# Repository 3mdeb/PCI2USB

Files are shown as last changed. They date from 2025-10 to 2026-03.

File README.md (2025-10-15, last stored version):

CERN Open Hardware Licence v1.2 or later

Preamble

Through this CERN Open Hardware Licence ("CERN OHL") version 1.2, CERN
wishes to provide a tool to foster collaboration and sharing among
hardware designers.  The CERN OHL is copyright CERN. Anyone is welcome
to use the CERN OHL, in unmodified form only, for the distribution of
their own Open Hardware designs. Any other right is reserved. Release
of hardware designs under the CERN OHL does not constitute an
endorsement of the licensor or its designs nor does it imply any
involvement by CERN in the development of such designs.

1. Definitions

In this Licence, the following terms have the following meanings:
 
“Licence” means this CERN OHL.

“Documentation” means schematic diagrams, designs, circuit or circuit
board layouts, mechanical drawings, flow charts and descriptive text,
and other explanatory material that is explicitly stated as being made
available under the conditions of this Licence. The Documentation may
be in any medium, including but not limited to computer files and
representations on paper, film, or any other media.

“Documentation Location” means a location where the Licensor has
placed Documentation, and which he believes will be publicly
accessible for at least three years from the first communication to
the public or distribution of Documentation.

“Product” means either an entire, or any part of a, device built using
the Documentation or the modified Documentation.

“Licensee” means any natural or legal person exercising rights under
this Licence.

“Licensor” means any natural or legal person that creates or modifies
Documentation and subsequently communicates to the public and/ or
distributes the resulting Documentation under the terms and conditions
of this Licence.

A Licensee may at the same time be a Licensor, and vice versa. 

Use of the masculine gender includes the feminine and neuter genders
and is employed solely to facilitate reading.

2. Applicability

2.1. This Licence governs the use, copying, modification,
communication to the public and distribution of the Documentation, and
the manufacture and distribution of Products. By exercising any right
granted under this Licence, the Licensee irrevocably accepts these
terms and conditions.

2.2. This Licence is granted by the Licensor directly to the Licensee,
and shall apply worldwide and without limitation in time. The Licensee
may assign his licence rights or grant sub-licences.

2.3. This Licence does not extend to software, firmware, or code
loaded into programmable devices which may be used in conjunction with
the Documentation, the modified Documentation or with Products, unless
such software, firmware, or code is explicitly expressed to be subject
to this Licence. The use of such software, firmware, or code is
otherwise subject to the applicable licence terms and conditions.

3. Copying, modification, communication to the public and distribution
of the Documentation

3.1. The Licensee shall keep intact all copyright and trademarks
notices, all notices referring to Documentation Location, and all
notices that refer to this Licence and to the disclaimer of warranties
that are included in the Documentation. He shall include a copy
thereof in every copy of the Documentation or, as the case may be,
modified Documentation, that he communicates to the public or
distributes.

3.2. The Licensee may copy, communicate to the public and distribute
verbatim copies of the Documentation, in any medium, subject to the
requirements specified in section 3.1.

3.3. The Licensee may modify the Documentation or any portion thereof
provided that upon modification of the Documentation, the Licensee
shall make the modified Documentation available from a Documentation
Location such that it can be easily located by an original Licensor
once the Licensee communicates to the public or distributes the
modified Documentation under section 3.4, and, where required by
section 4.1, by a recipient of a Product. However, the Licensor shall
not assert his rights under the foregoing proviso unless or until a
Product is distributed.

3.4. The Licensee may communicate to the public and distribute the
modified Documentation (thereby in addition to being a Licensee also
becoming a Licensor), always provided that he shall:

a) comply with section 3.1;

b) cause the modified Documentation to carry prominent notices stating
that the Licensee has modified the Documentation, with the date and
description of the modifications;

c) cause the modified Documentation to carry a new Documentation
Location notice if the original Documentation provided for one;

d) make available the modified Documentation at the same level of
abstraction as that of the Documentation, in the preferred format for
making modifications to it (e.g. the native format of the CAD tool as
applicable), and in the event that format is proprietary, in a format
viewable with a tool licensed under an OSI-approved license if the
proprietary tool can create it; and

e) license the modified Documentation under the terms and conditions
of this Licence or, where applicable, a later version of this Licence
as may be issued by CERN.

3.5. The Licence includes a non-exclusive licence to those patents or
registered designs that are held by, under the control of, or
sub-licensable by the Licensor, to the extent necessary to make use of
the rights granted under this Licence. The scope of this section 3.5
shall be strictly limited to the parts of the Documentation or
modified Documentation created by the Licensor.

4. Manufacture and distribution of Products

4.1. The Licensee may manufacture or distribute Products always
provided that, where such manufacture or distribution requires a
licence under this Licence the Licensee provides to each recipient of
such Products an easy means of accessing a copy of the Documentation
or modified Documentation, as applicable, as set out in section 3.

4.2. The Licensee is invited to inform any Licensor who has indicated
his wish to receive this information about the type, quantity and
dates of production of Products the Licensee has (had) manufactured

5. Warranty and liability

5.1. DISCLAIMER – The Documentation and any modified Documentation are
provided "as is" and any express or implied warranties, including, but
not limited to, implied warranties of merchantability, of satisfactory
quality, non-infringement of third party rights, and fitness for a
particular purpose or use are disclaimed in respect of the
Documentation, the modified Documentation or any Product. The Licensor
makes no representation that the Documentation, modified
Documentation, or any Product, does or will not infringe any patent,
copyright, trade secret or other proprietary right. The entire risk as
to the use, quality, and performance of a Product shall be with the
Licensee and not the Licensor. This disclaimer of warranty is an
essential part of this Licence and a condition for the grant of any
rights granted under this Licence. The Licensee warrants that it does
not act in a consumer capacity.

5.2. LIMITATION OF LIABILITY – The Licensor shall have no liability
for direct, indirect, special, incidental, consequential, exemplary,
punitive or other damages of any character including, without
limitation, procurement of substitute goods or services, loss of use,
data or profits, or business interruption, however caused and on any
theory of contract, warranty, tort (including negligence), product
liability or otherwise, arising in any way in relation to the
Documentation, modified Documentation and/or the use, manufacture or
distribution of a Product, even if advised of the possibility of such
damages, and the Licensee shall hold the Licensor(s) free and harmless
from any liability, costs, damages, fees and expenses, including
claims by third parties, in relation to such use.

6. General

6.1. Except for the rights explicitly granted hereunder, this Licence
does not imply or represent any transfer or assignment of intellectual
property rights to the Licensee.

6.2. The Licensee shall not use or make reference to any of the names
(including acronyms and abbreviations), images, or logos under which
the Licensor is known, save in so far as required to comply with
section 3. Any such permitted use or reference shall be factual and
shall in no event suggest any kind of endorsement by the Licensor or
its personnel of the modified Documentation or any Product, or any
kind of implication by the Licensor or its personnel in the
preparation of the modified Documentation or Product.

6.3. CERN may publish updated versions of this Licence which retain
the same general provisions as this version, but differ in detail so
far this is required and reasonable. New versions will be published
with a unique version number.

6.4. This Licence shall terminate with immediate effect, upon written
notice and without involvement of a court if the Licensee fails to
comply with any of its terms and conditions, or if the Licensee
initiates legal action against Licensor in relation to this
Licence. Section 5 shall continue to apply.

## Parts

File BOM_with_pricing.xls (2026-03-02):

 | References | Description | Mfr | Mfr PN | Value | Footprint | Quantity | Datasheet | Price per Unit(1) | Price per Unit(100) | TOTAL(1) | TOTAL(100)
1 | C1, C2, C3, C7, C34, C56 | X5R, 10%, 6.3V | Samsung Electro-Mechanics | CL21A226KQCLRNC | 22 μF | 0805 | 6 | https://www.samsungsem.com/resources/file/global/support/product_catalog/MLCC.pdf | 0.48 PLN | 0.15 PLN | 2.88 PLN | 0.90 PLN
2 | C17, C18, C19, C20, C21 | X5R, 10%, 6.3V | Samsung Electro-Mechanics | CL05A226MQ5N6J8 | 22 μF | 0402 | 5 | https://mm.digikey.com/Volume0/opasdata/d220001/medias/docus/61/CL05A226MQ5N6J8_Spec.pdf | 1.81 PLN | 1.36 PLN | 9.05 PLN | 6.80 PLN
3 | C12, C13 | Electrolytic, 20%, 10V | Panasonic | EEE-FK1A151P | 150 μF | 6,3 mm x 5.8 mm | 2 | https://industrial.panasonic.com/cdbs/www-data/pdf/RDE0000/ABA0000C1184.pdf | 1.81 PLN | 0.74 PLN | 3.62 PLN | 1.48 PLN
4 | C16 | X7R, 10%, 10V | Vishay | VJ0402Y102KXQCW1BC | 1000 pF | 0402 | 1 | https://www.vishay.com/doc?28548 | 0.44 PLN | 0.11 PLN | 0.44 PLN | 0.11 PLN
5 | C22, C25, C28, C31, C37, C40, C43, C46, C49, C57 | X7R, 10%, 6.3V | Murata Electronics | GRM155R70J103KA01D | 0.01 μF | 0402 | 10 | https://search.murata.co.jp/Ceramy/image/img/A01X/G101/ENG/GRM155R70J103KA01-01A.pdf | 0.37 PLN | 0.06 PLN | 3.70 PLN | 0.60 PLN
6 | C35, C36 | X8R, 10%, 10V | KEMET | C0402C180K8HACAUTO | 18 pF | 0402 | 2 | https://www.mouser.pl/datasheet/3/508/1/KEM_C1007_X8R_ULTRA_150C_SMD.pdf | 0.40 PLN | 0.11 PLN | 0.80 PLN | 0.22 PLN
7 | C4 | X7R, 10%, 6.3V | Murata Electronics | GRM21BR70J106KA73K | 10 μF | 0805 | 1 | https://search.murata.co.jp/Ceramy/image/img/A01X/G101/ENG/GRM21BR70J106KA73-01A.pdf | 0.48 PLN | 0.15 PLN | 0.48 PLN | 0.15 PLN
8 | C5 | NOT POPULATED | - | - | - | 0402 | 0 | - | 0.00 PLN | 0.00 PLN | 0.00 PLN | 0.00 PLN
9 | C6, C8, C9, C10, C11, C14, C15, C23, C24, C26, C27, C29, C30, C32, C33 C41, C42, C44, C45, C47, C48, C50, C51, C52, C53, C54, C55 | X7R, 10%, 6.3V | Murata Electronics | GRM155R70J104KA01D | 0.1 μF | 0402 | 26 | https://www.mouser.pl/datasheet/3/76/1/GRM155R70J104KA01-01A.pdf | 0.37 PLN | 0.06 PLN | 9.62 PLN | 1.56 PLN
10 | D2 | 110pF, 120W | Panjit | PJSD05TS-AU_R1_000A1 | 6V/9V/5A | SOD-523-2 | 1 | https://www.mouser.pl/datasheet/3/3736/1/FFA64C26C476D1F4CE6B232A1F1091977EEA37920C5E016FF7236D6CCD3F512B.pdf | 0.63 PLN | 0.20 PLN | 0.63 PLN | 0.20 PLN
11 | D3 | 300pF, 120W | Panjit | PJSD03TS-AU_R1_000A1 | 4V/6.5V/5A | SOD-523-2 | 1 | https://www.mouser.pl/datasheet/3/3736/1/3946363437334643344438333636453735383137424443343037353234384636.pdf | 0.85 PLN | 0.27 PLN | 0.85 PLN | 0.27 PLN
12 | D4 | LED, RED | Kingbright | APHD1608LSURCK | RED | 0603 | 1 | https://www.mouser.pl/datasheet/3/308/1/APHD1608LSURCK.pdf | 1.26 PLN | 0.60 PLN | 1.26 PLN | 0.60 PLN
13 | D6, D7 | LED, GREEN | Kingbright | APHD1608LCGCK | GREEN | 0603 | 2 | https://www.mouser.pl/datasheet/3/308/1/APHD1608LCGCK.pdf | 1.37 PLN | 0.65 PLN | 2.74 PLN | 1.30 PLN
14 | D8 | 2.3pF, 85W | Texas Instruments | ESDS304DBVR | 3.6V/4.5V/16A | SOT-23-5 | 1 | https://www.ti.com/lit/ds/symlink/esds302.pdf?ts=1764697688544 | 3.22 PLN | 1.30 PLN | 3.22 PLN | 1.30 PLN
15 | F1, F2 | Fast Act Fuse | Vishay | MFU0603FF05000P500 | 32VDC/5A | 0603 | 2 | https://www.vishay.com/docs/28747/mfuserie.pdf | 0.85 PLN | 0.60 PLN | 1.70 PLN | 1.20 PLN
16 | F3 | Fast Act Fuse | Vishay | MFU0603FF01000P500 | 32VDC/1A | 0603 | 1 | https://www.vishay.com/doc?28747 | 0.78 PLN | 0.55 PLN | 0.78 PLN | 0.55 PLN
17 | FB1 | Ferrite Bead | Murata | BLM18EG221SN1D | 220 Ohm, 2A | 0603 | 1 | https://www.mouser.pl/datasheet/3/76/1/ENFA0021.pdf | 0.85 PLN | 0.42 PLN | 0.85 PLN | 0.42 PLN
18 | FL1, FL2 | 25%, 5V | Panasonic | EXC-24CE900U | 90 Ohm 160mA | 0504 | 2 | https://industrial.panasonic.com/cdbs/www-data/pdf/AWE0000/AWE0000C207.pdf | 1.44 PLN | 0.98 PLN | 2.88 PLN | 1.96 PLN
19 | IC1 | USB HOST IC | Texas Instruments | TUSB7320 | 2 Port USB 3.0 | WQFN-100 | 1 | https://www.ti.com/lit/ds/symlink/tusb7340.pdf | 43.34 PLN | 29.03 PLN | 43.34 PLN | 29.03 PLN
20 | J1 | M.2 Edge Connector | - | - | - | - | 0 | - | 0.00 PLN | 0.00 PLN | 0.00 PLN | 0.00 PLN
21 | J2 | USB Internal Connector | Samtec | TSW-105-07-G-D-009 | 9 pin | 2.54mm pitch | 1 | https://suddendocs.samtec.com/catalog_english/tsw_th.pdf | 5.29 PLN | 3.29 PLN | 5.29 PLN | 3.29 PLN
22 | L1 | 20%, 5A | Pulse Electronics | BMRA000505151R0MA1 | 1 μH | 5.7 mm x 5.4 mm x 1.5 mm | 1 | https://www.mouser.pl/datasheet/3/508/1/BMRx_Series.pdf | 1.96 PLN | 1.33 PLN | 1.96 PLN | 1.33 PLN
23 | R1 | 1%, 200mW | Panasonic | ERJ-P03F7323V | 732Kohm | 0603 | 1 | https://industrial.panasonic.com/cdbs/www-data/pdf/RDO0000/AOA0000C331.pdf | 1.04 PLN | 0.33 PLN | 1.04 PLN | 0.33 PLN
24 | R10 | 1%, 100mW | Panasonic | ERJ-U02F9091X | 9.09 Kohm | 0402 | 1 | https://industrial.panasonic.com/cdbs/www-data/pdf/RDP0000/AOA0000C334.pdf | 0.44 PLN | 0.08 PLN | 0.44 PLN | 0.08 PLN
25 | R11, R12, R13, R14 | NOT POPULATED | - | - | - | 0402 | 0 | - | 0.00 PLN | 0.00 PLN | 0.00 PLN | 0.00 PLN
26 | R15, R16 | NOT POPULATED | - | - | - | 0402 | 0 | - | 0.00 PLN | 0.00 PLN | 0.00 PLN | 0.00 PLN
27 | R17 | 1%, 100mW | Panasonic | ERJ-2RKF3092X | 30.9 Kohm | 0402 | 1 | https://industrial.panasonic.com/cdbs/www-data/pdf/RDA0000/AOA0000C304.pdf | 0.37 PLN | 0.03 PLN | 0.37 PLN | 0.03 PLN
28 | R2, R29 | 5%, 200mW | Panasonic | ERJ-PA2J104X | 100 Kohm | 0402 | 2 | https://industrial.panasonic.com/cdbs/www-data/pdf/RDO0000/AOA0000C331.pdf | 0.48 PLN | 0.20 PLN | 0.96 PLN | 0.40 PLN
29 | R20, R21 | 1%, 63mW | Vishay | CRCW0402680RFKEDC | 680 Ohm | 0402 | 2 | https://www.vishay.com/docs/20035/dcrcwe3.pdf | 0.37 PLN | 0.04 PLN | 0.74 PLN | 0.08 PLN
30 | R22 | NOT POPULATED | - | - | - | 0402 | 0 | - | 0.00 PLN | 0.00 PLN | 0.00 PLN | 0.00 PLN
31 | R24, R25, R28 | 1%, 100mW | Panasonic | ERJ-2GE0R00X | 0 Ohm | 0402 | 3 | https://industrial.panasonic.com/cdbs/www-data/pdf/RDA0000/AOA0000C301.pdf | 0.37 PLN | 0.03 PLN | 1.11 PLN | 0.09 PLN
32 | R27 | 1%, 100mW | Panasonic | ERJ-2RKF1004X | 1 Mohm | 0402 | 1 | https://industrial.panasonic.com/cdbs/www-data/pdf/RDA0000/AOA0000C304.pdf | 0.37 PLN | 0.03 PLN | 0.37 PLN | 0.03 PLN
33 | R4 | 1%, 63mW | Vishay | CRCW04021K50FKEDC | 1.5 Kohm | 0402 | 1 | https://www.vishay.com/docs/20035/dcrcwe3.pdf | 0.37 PLN | 0.04 PLN | 0.37 PLN | 0.04 PLN
34 | R5 | 0.05%, 62.5mW | Panasonic | ERJ-2RHD4991X | 4.99 Kohm | 0402 | 1 | https://industrial.panasonic.com/cdbs/www-data/pdf/RDA0000/AOA0000C304.pdf | 0.52 PLN | 0.11 PLN | 0.52 PLN | 0.11 PLN
35 | R6 | 1%, 100mW | Panasonic | ERJ-2RKF1871X | 1.87 Kohm | 0402 | 1 | https://industrial.panasonic.com/cdbs/www-data/pdf/RDA0000/AOA0000C304.pdf | 0.37 PLN | 0.04 PLN | 0.37 PLN | 0.04 PLN
36 | R7, R18, R19, R23 | 1%, 100mW | Panasonic | ERJ-2RKF1002X | 10 Kohm | 0402 | 4 | https://industrial.panasonic.com/cdbs/www-data/pdf/RDA0000/AOA0000C304.pdf | 0.40 PLN | 0.04 PLN | 1.60 PLN | 0.16 PLN
37 | R8, R26 | 1%, 100mW | Panasonic | ERJ-2RKF4701X | 4.7 Kohm | 0402 | 2 | https://industrial.panasonic.com/cdbs/www-data/pdf/RDA0000/AOA0000C304.pdf | 0.37 PLN | 0.04 PLN | 0.74 PLN | 0.08 PLN
38 | U1 | Boost Converter | Texas Instruments | TPS61023DRLR | 3.3V to 5V 3.7 A | SOT-563-6 | 1 | https://www.ti.com/lit/ds/symlink/tps61023.pdf | 4.07 PLN | 2.33 PLN | 4.07 PLN | 2.33 PLN
39 | U2 | Power Switch IC | Texas Instruments | TPS2560DRC | 2 Out, 5V, 2.5A | VSON-10 | 1 | https://www.ti.com/lit/ds/symlink/tps2560.pdf?ts=1763292158337 | 5.25 PLN | 3.08 PLN | 5.25 PLN | 3.08 PLN
40 | U3 | Voltage Regulator | Texas Instruments | TPS74401RGWRM3 | 3.3V to 1.1V 3 A | VQFN-20 | 1 | https://www.ti.com/lit/gpn/tps74401 | 6.97 PLN | 3.26 PLN | 6.97 PLN | 3.26 PLN
41 | Y1 | 18 pF, 50 Ohm | ABRACON | ABM3B-48.000MHZ-B2-T | 48 MHz | 5 mm x 3.2 mm | 1 | https://www.mouser.pl/datasheet/3/184/1/abm3b.pdf | 2.70 PLN | 1.93 PLN | 2.70 PLN | 1.93 PLN
 |  |  |  |  |  |  |  |  |  | Total: | 123.71 PLN | 65.34 PLN

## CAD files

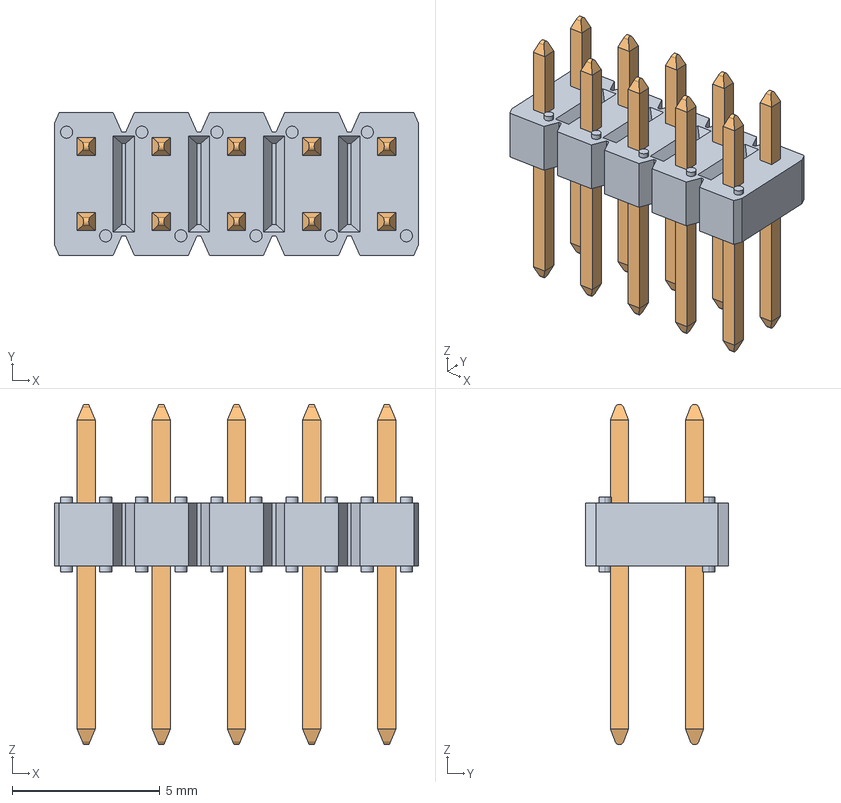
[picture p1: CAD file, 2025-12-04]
Kicad-Files/Custom Libraries/3dmodels/TSW-105-07-G-D-009.stp
12.3 x 4.83 x 11.5 mm
77310_Y16 x 10

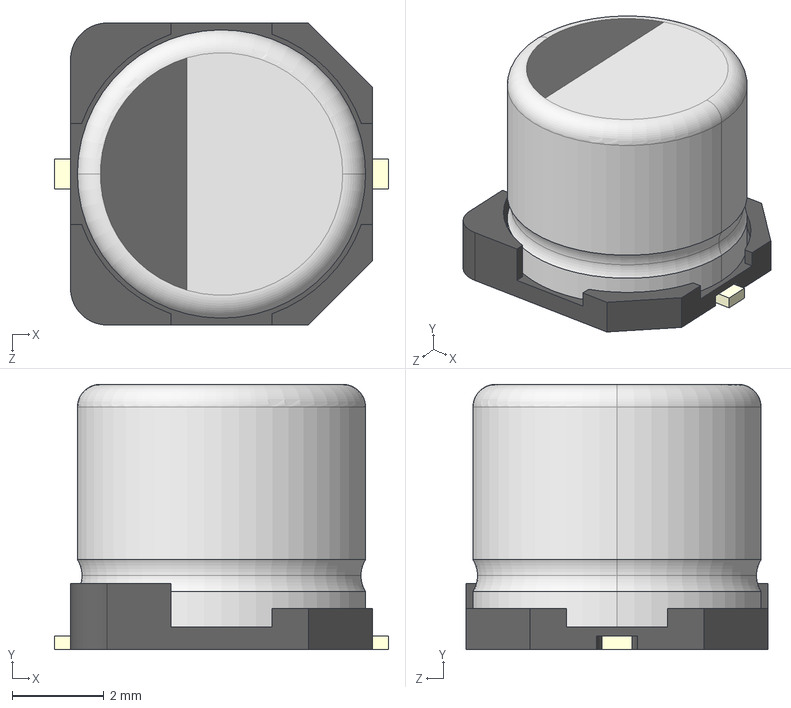
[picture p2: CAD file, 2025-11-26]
Kicad-Files/Custom Libraries/3dmodels/EEE-FK1A151P.stp
7.30 x 5.80 x 6.60 mm
標準SIZE CODE D-001
標準SIZE CODE D-002
標準SIZE CODE D-003 x 2

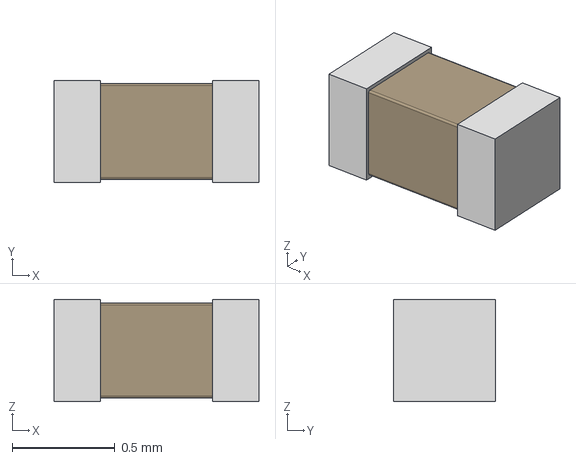
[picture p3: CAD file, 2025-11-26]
Kicad-Files/Custom Libraries/3dmodels/capacitor0402.stp
1.00 x 0.5 x 0.5 mm

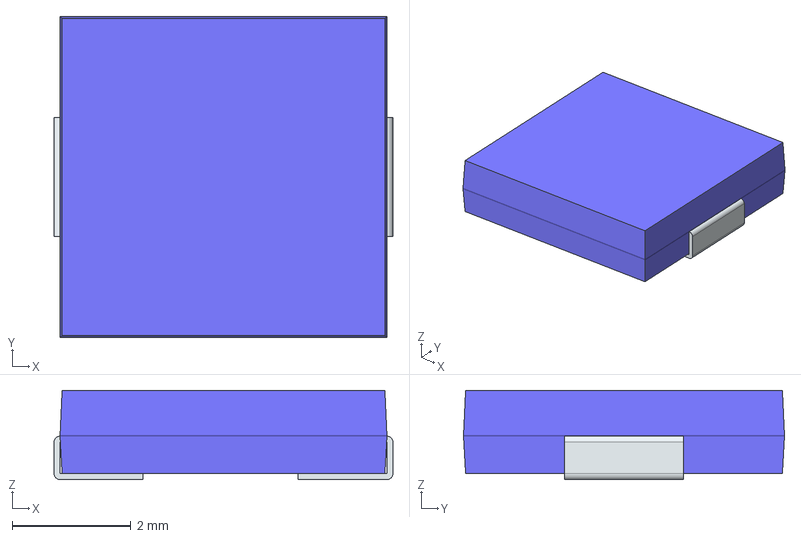
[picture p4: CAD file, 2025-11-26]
Kicad-Files/Custom Libraries/3dmodels/BMRA00050515R47MA1.stp
5.70 x 5.40 x 1.50 mm
FilletPin1
FilletPin2

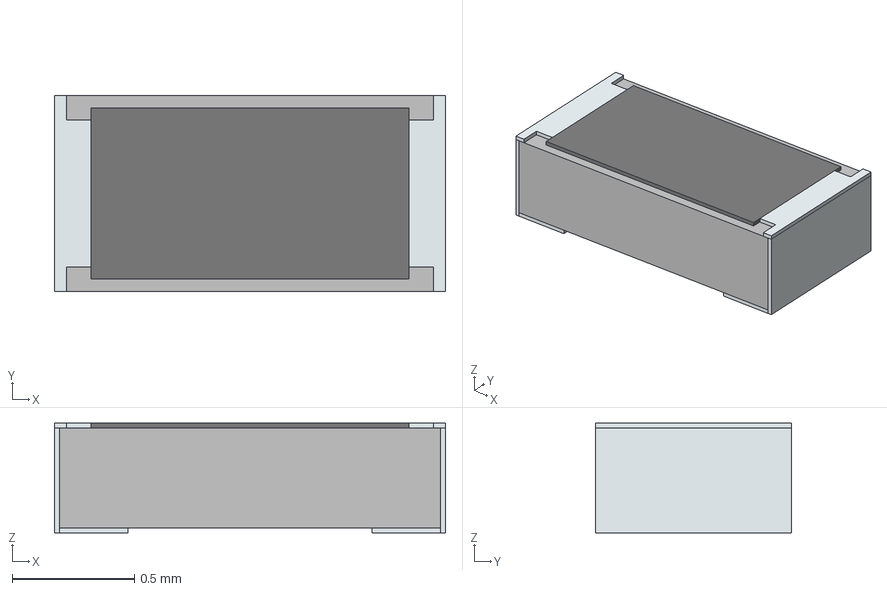
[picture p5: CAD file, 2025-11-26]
Kicad-Files/Custom Libraries/3dmodels/resistor0603.stp
1.60 x 0.8 x 0.45 mm
solidBody
solidTop
solidTerminal2
solidTerminal1
solidTerminal3

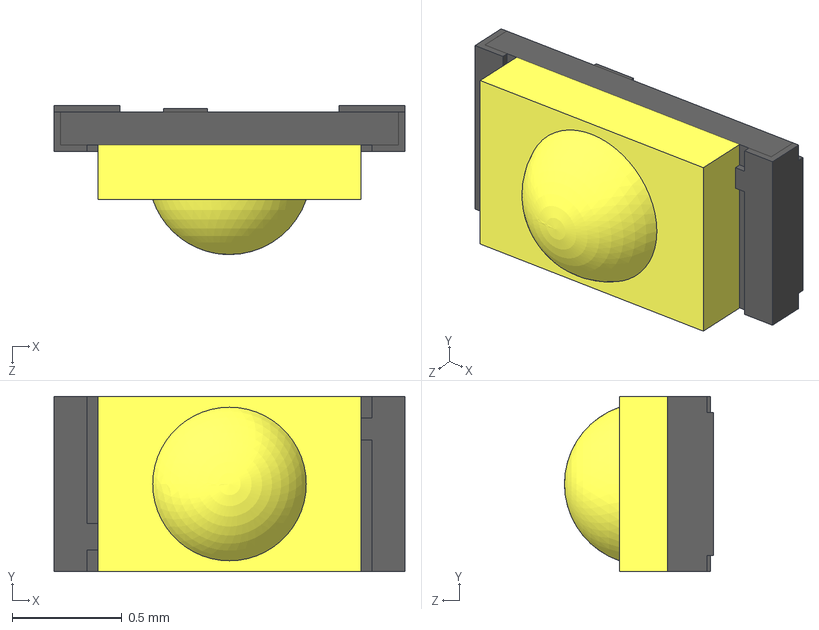
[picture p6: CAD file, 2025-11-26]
Kicad-Files/Custom Libraries/3dmodels/APHD1608LCGCK.stp
1.60 x 0.8 x 0.68 mm

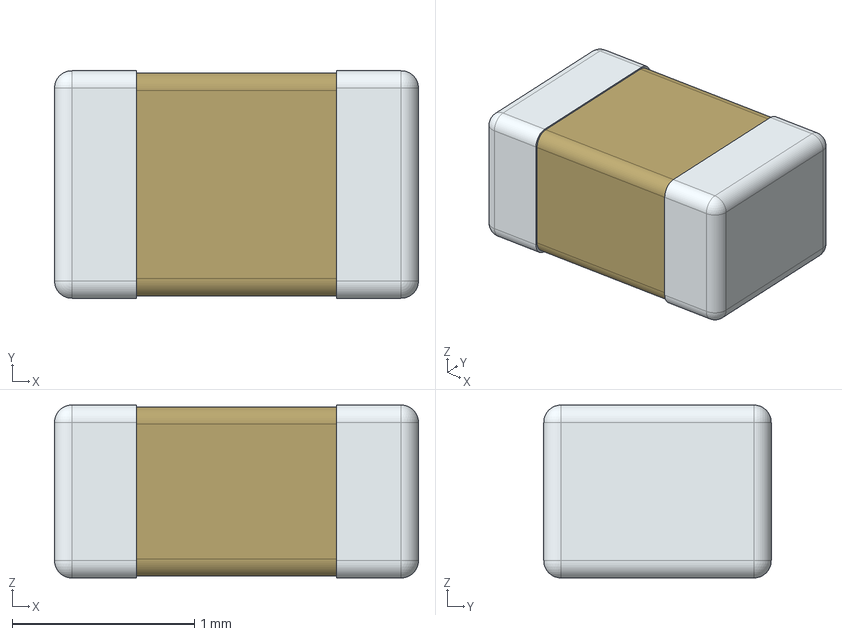
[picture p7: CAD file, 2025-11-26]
Kicad-Files/Custom Libraries/3dmodels/capacitor0805.stp
2.00 x 1.25 x 0.95 mm

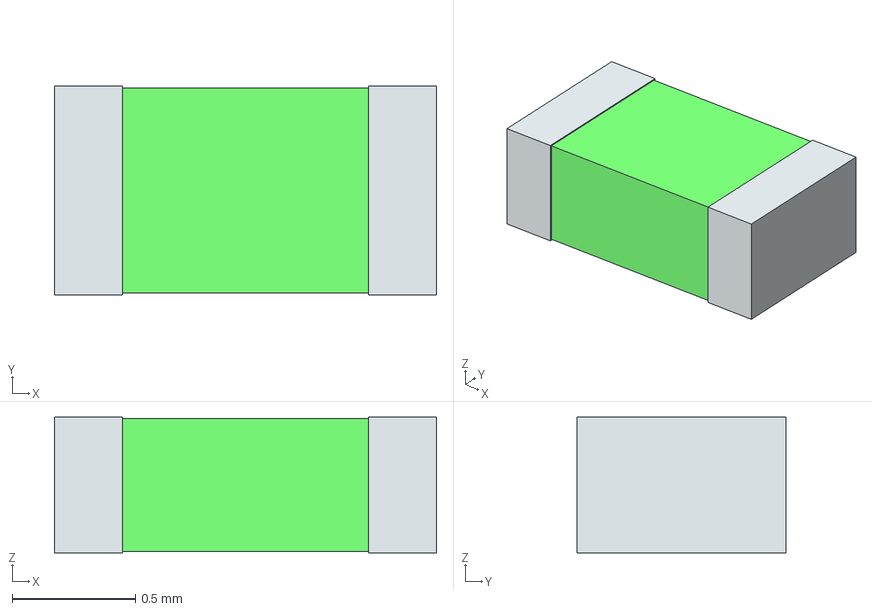
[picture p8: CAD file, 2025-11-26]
Kicad-Files/Custom Libraries/3dmodels/fuse0603.stp
1.55 x 0.85 x 0.55 mm
term1
term2

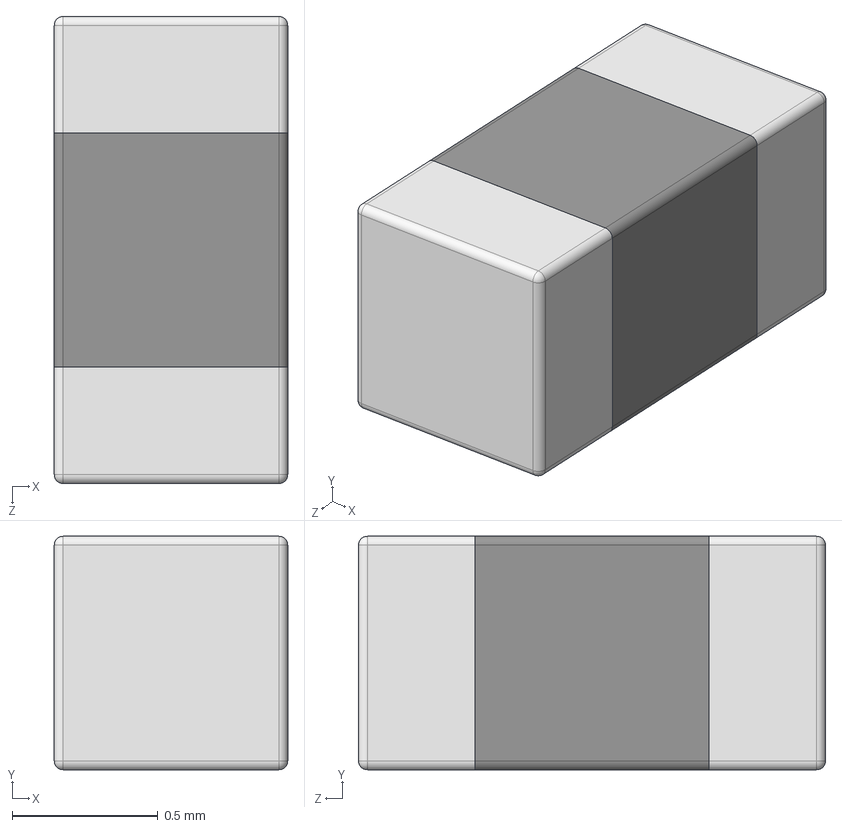
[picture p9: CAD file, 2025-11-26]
Kicad-Files/Custom Libraries/3dmodels/BLM18EG221SN1D.stp
0.8 x 0.8 x 1.60 mm

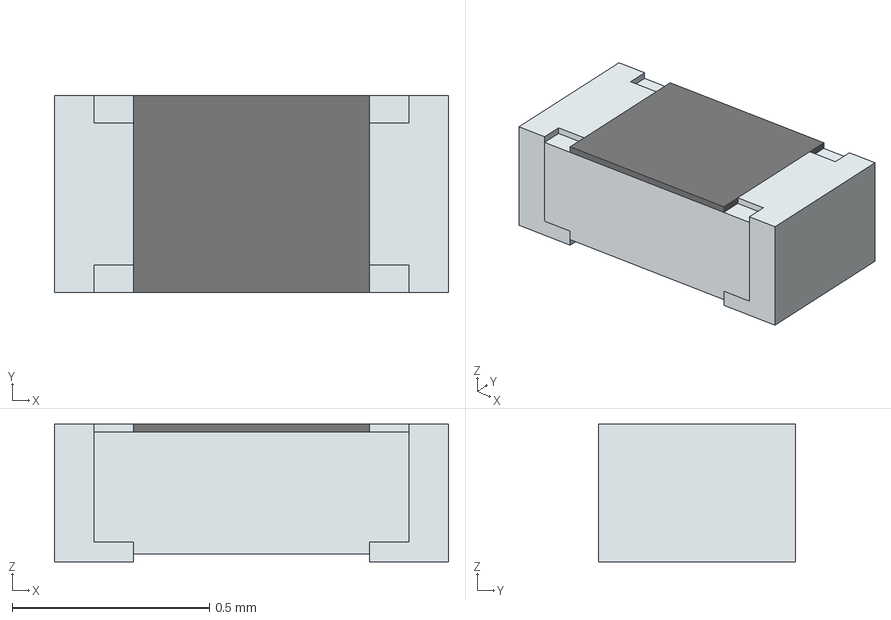
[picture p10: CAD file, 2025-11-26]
Kicad-Files/Custom Libraries/3dmodels/resistor0402.stp
1.00 x 0.5 x 0.35 mm
solidBody
Terminal
solidTop

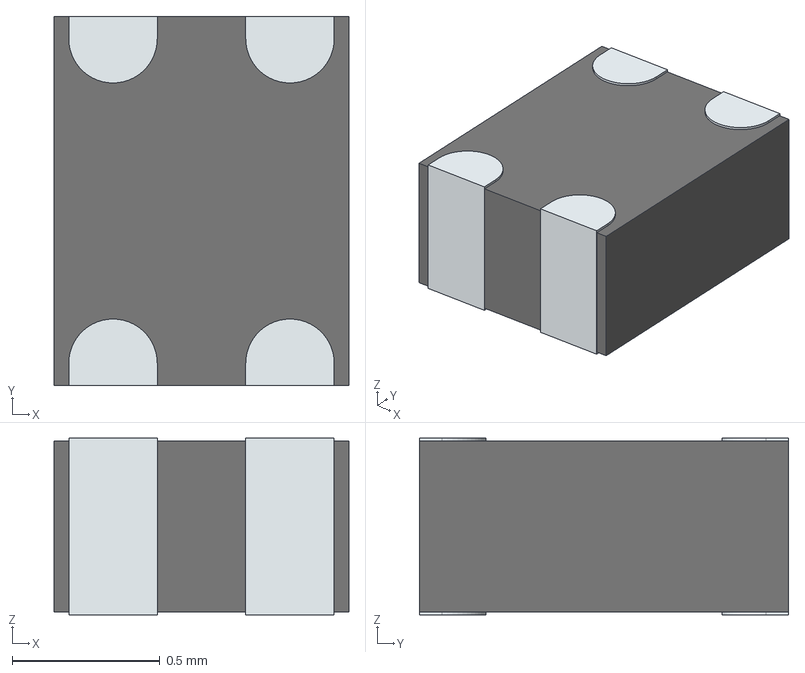
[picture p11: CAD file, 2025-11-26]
Kicad-Files/Custom Libraries/3dmodels/EXC-24CE900U.stp
1.00 x 1.25 x 0.6 mm
Rect1
solidTerminal

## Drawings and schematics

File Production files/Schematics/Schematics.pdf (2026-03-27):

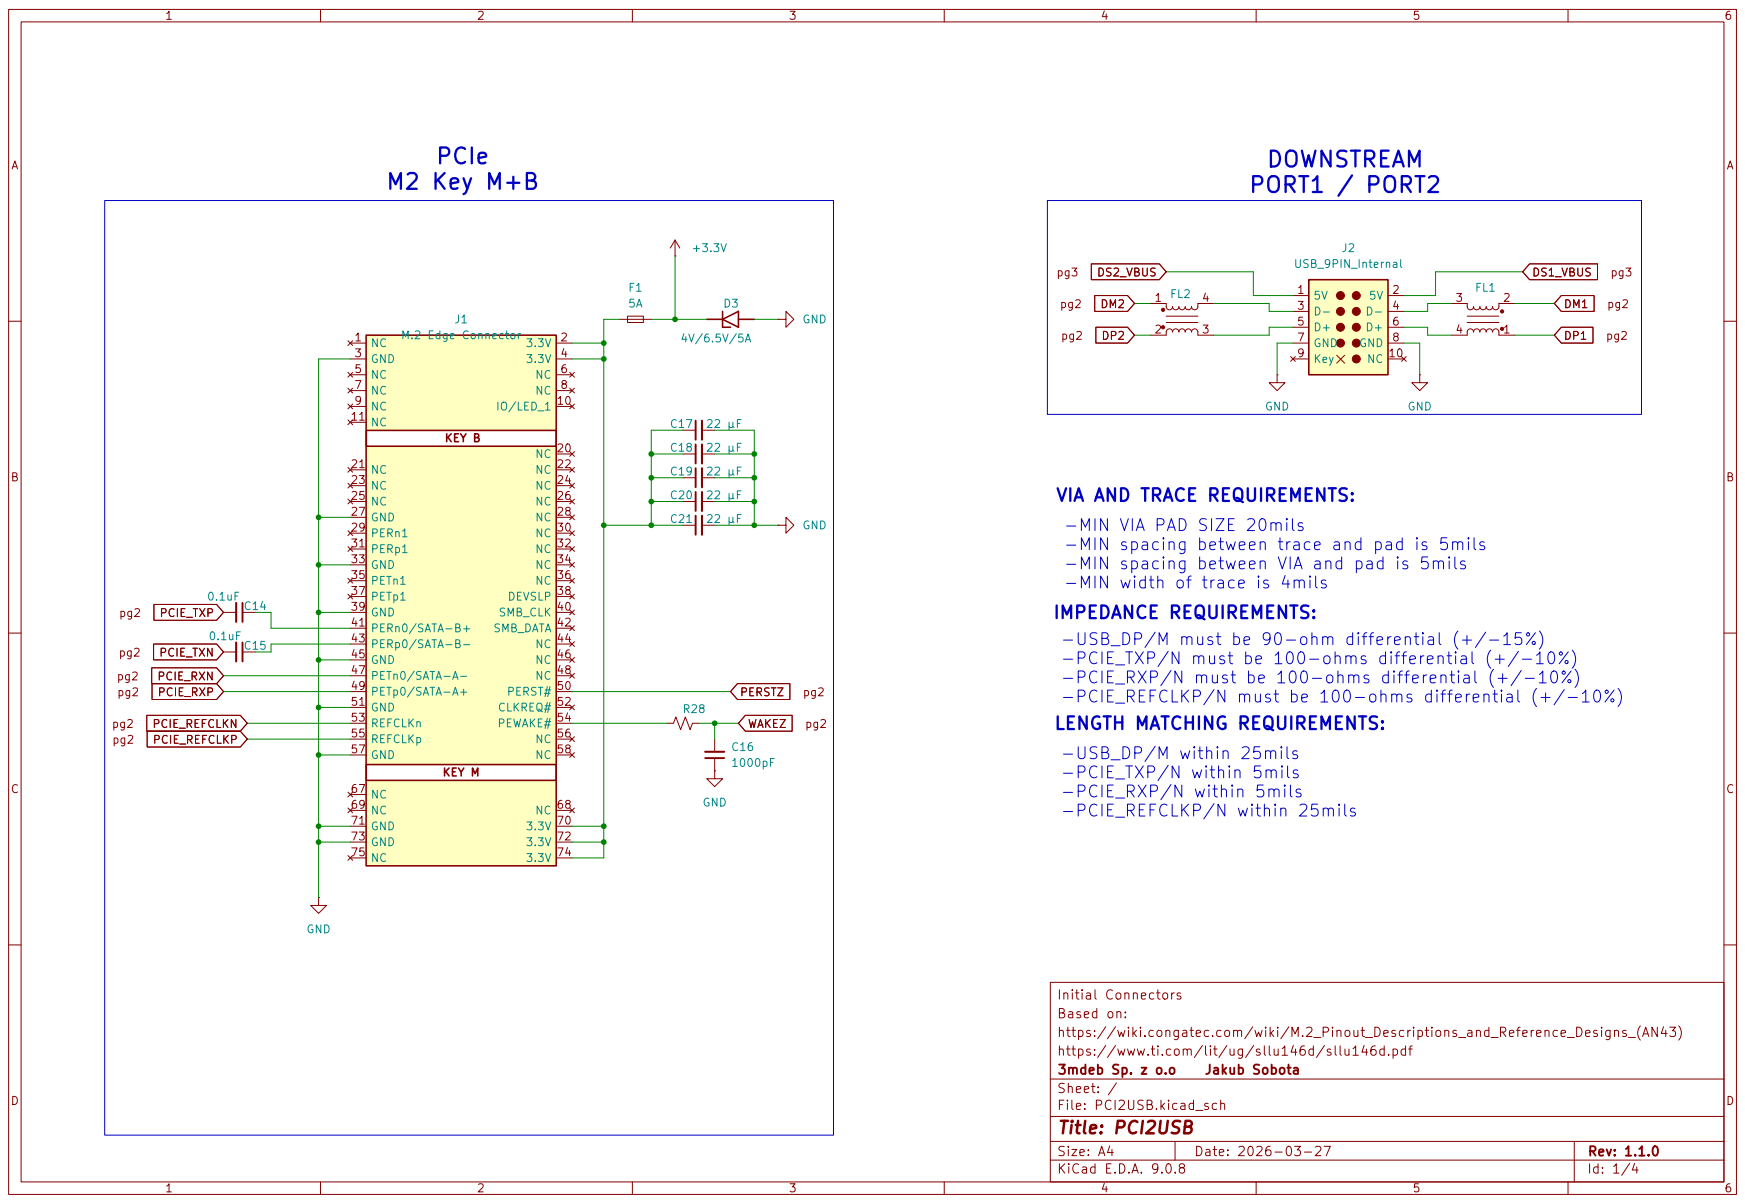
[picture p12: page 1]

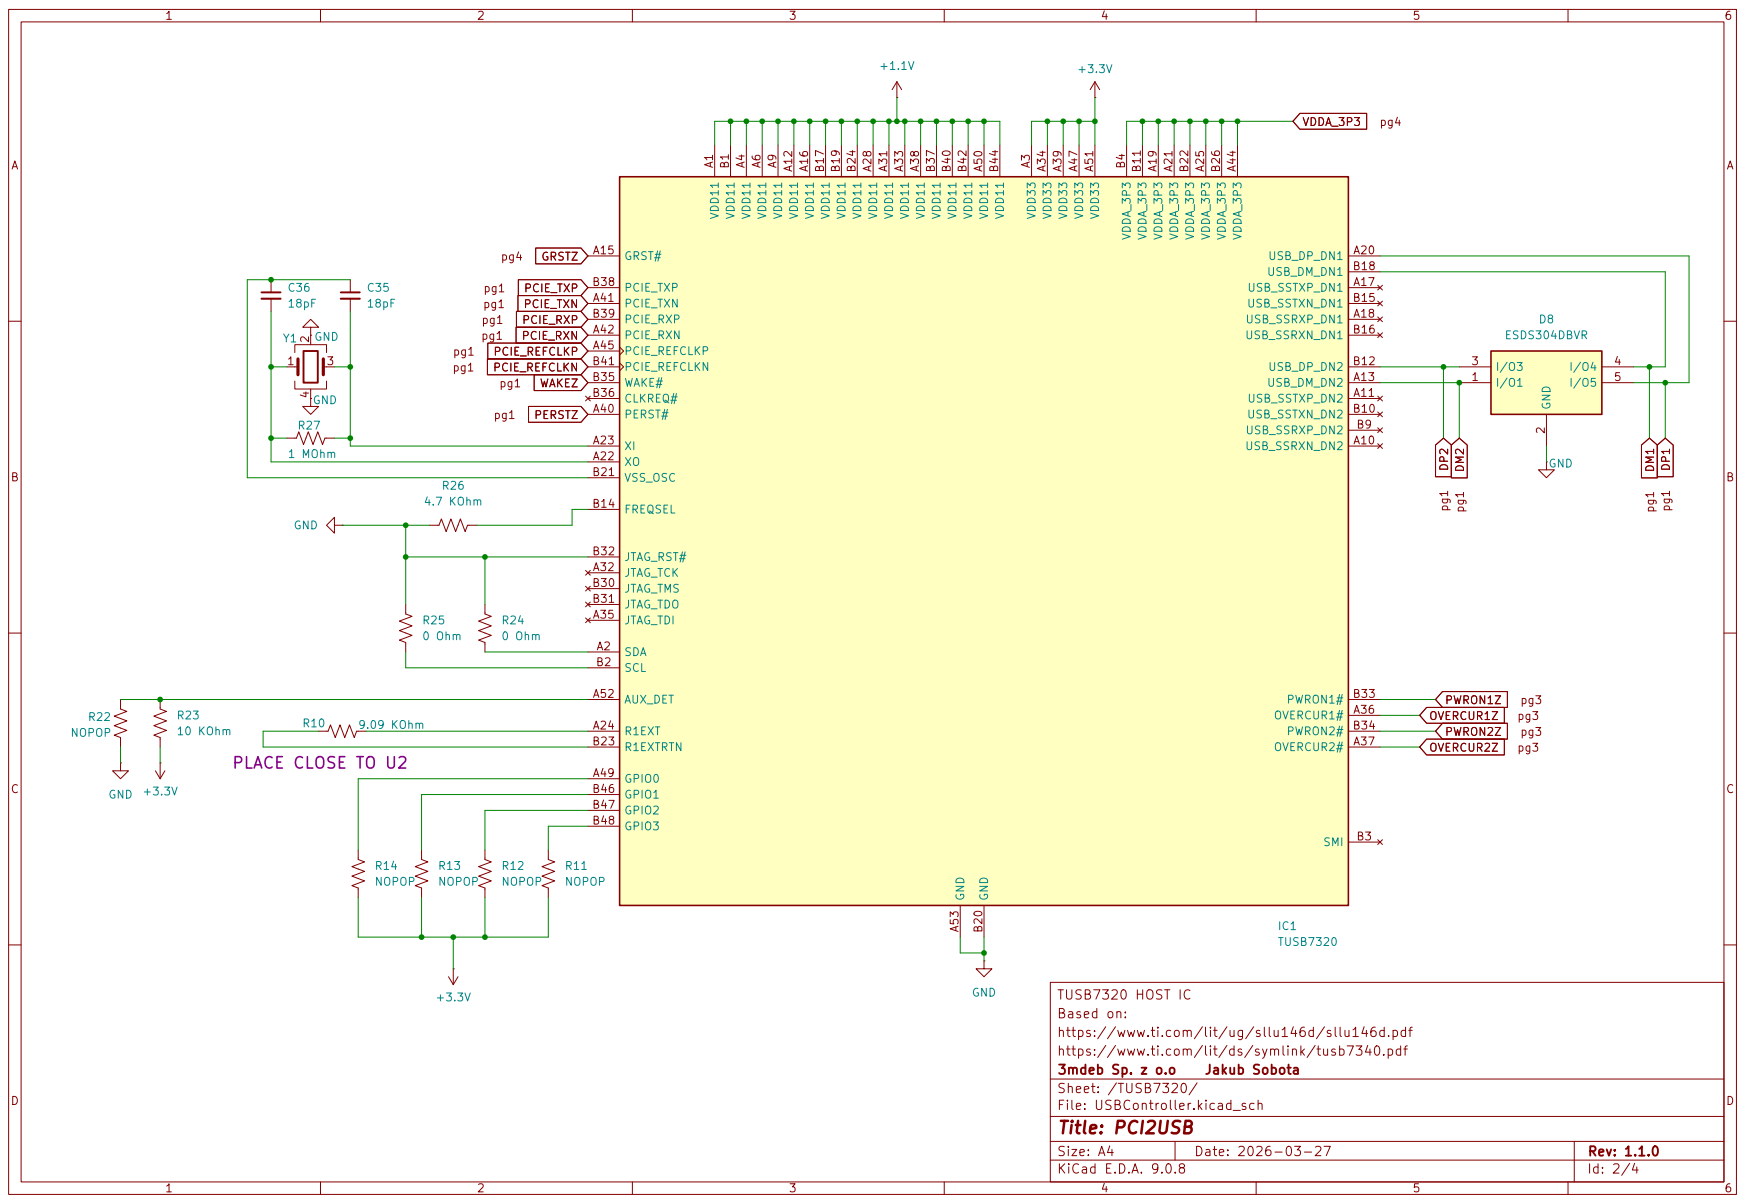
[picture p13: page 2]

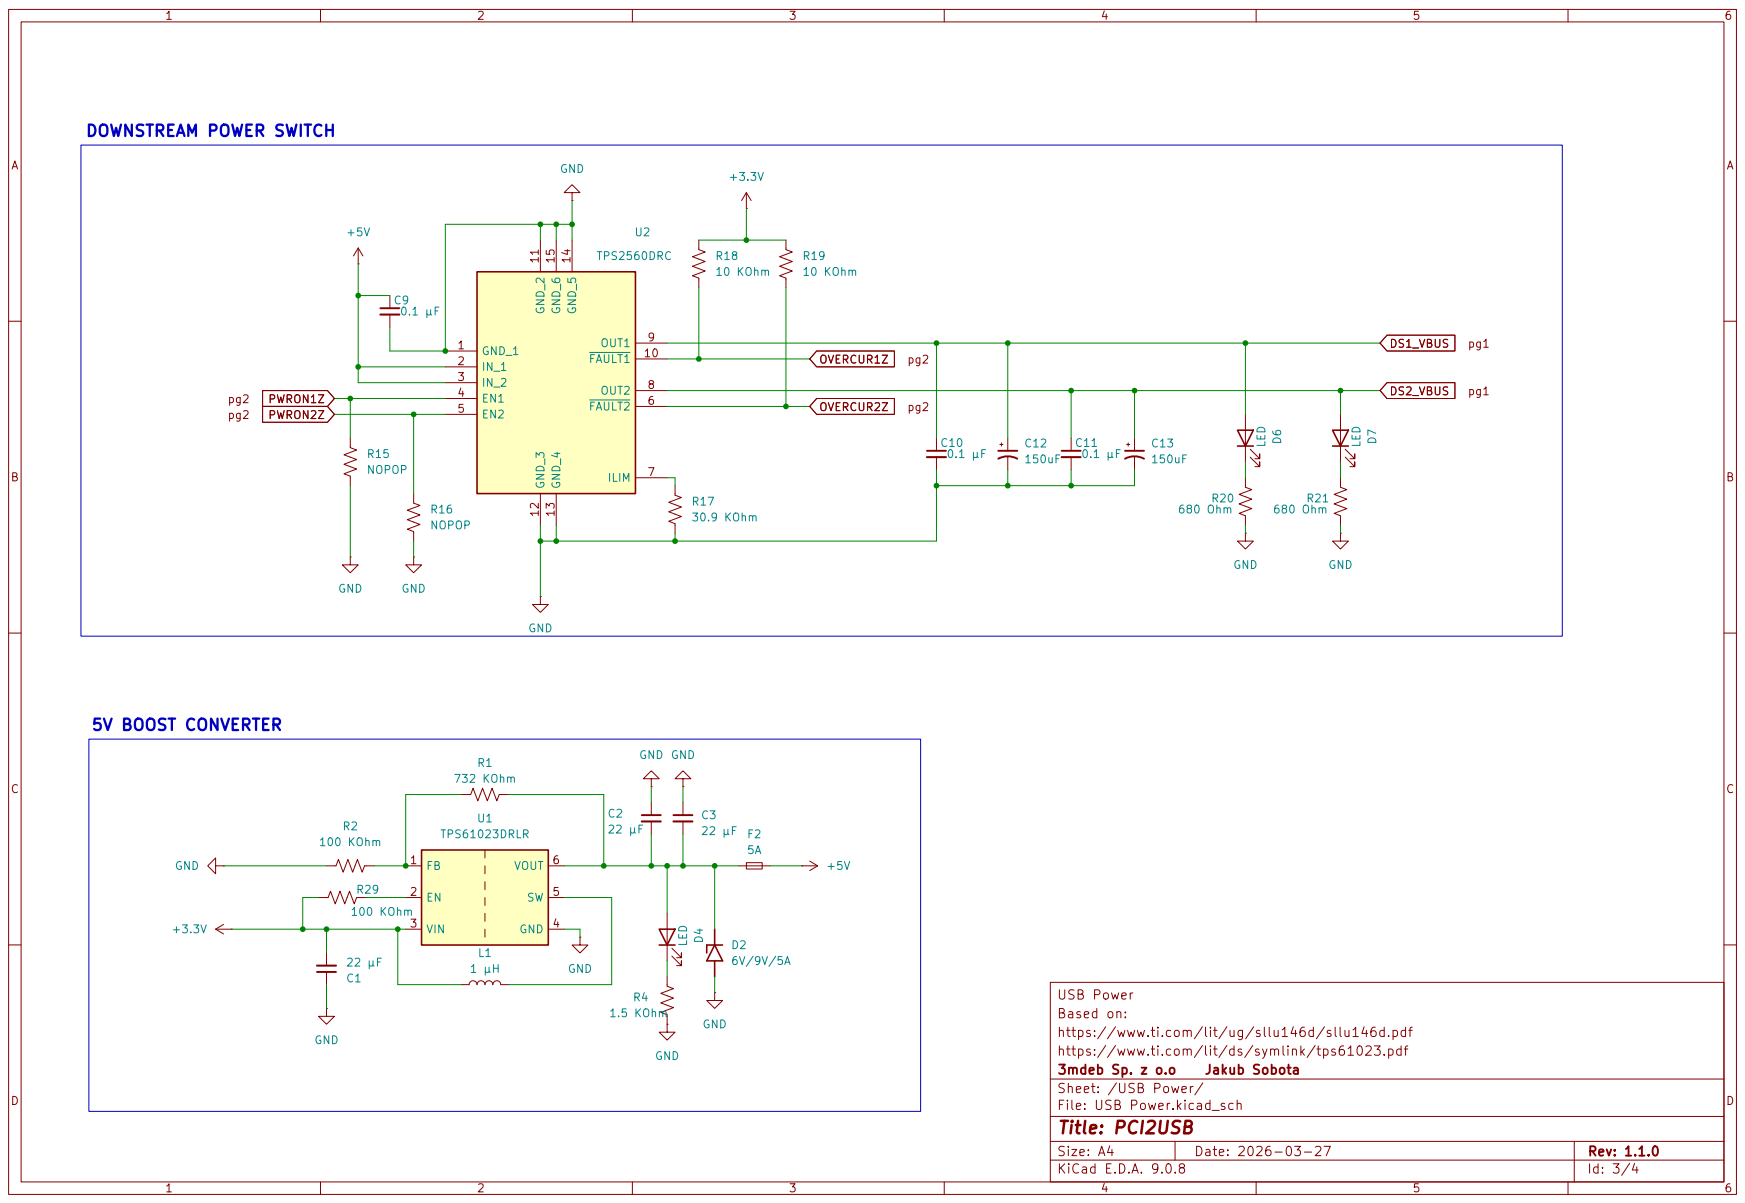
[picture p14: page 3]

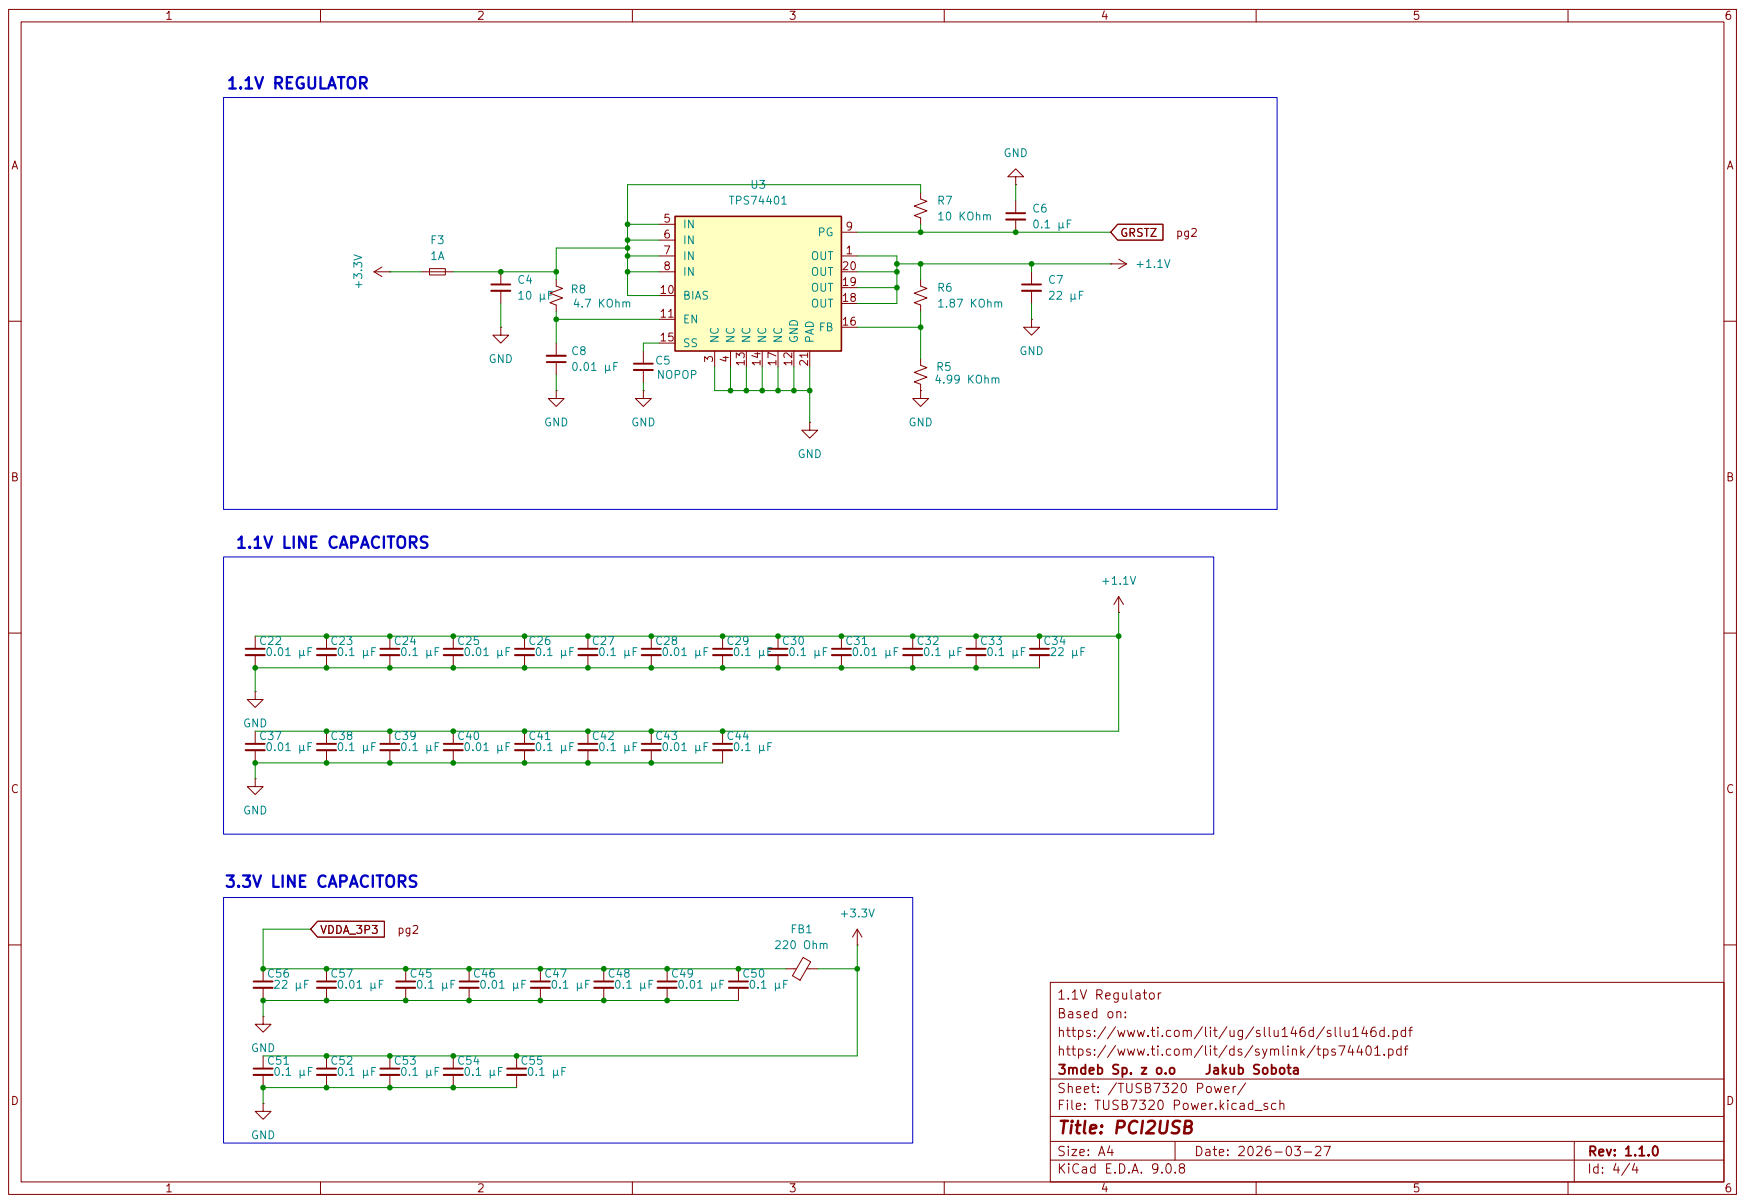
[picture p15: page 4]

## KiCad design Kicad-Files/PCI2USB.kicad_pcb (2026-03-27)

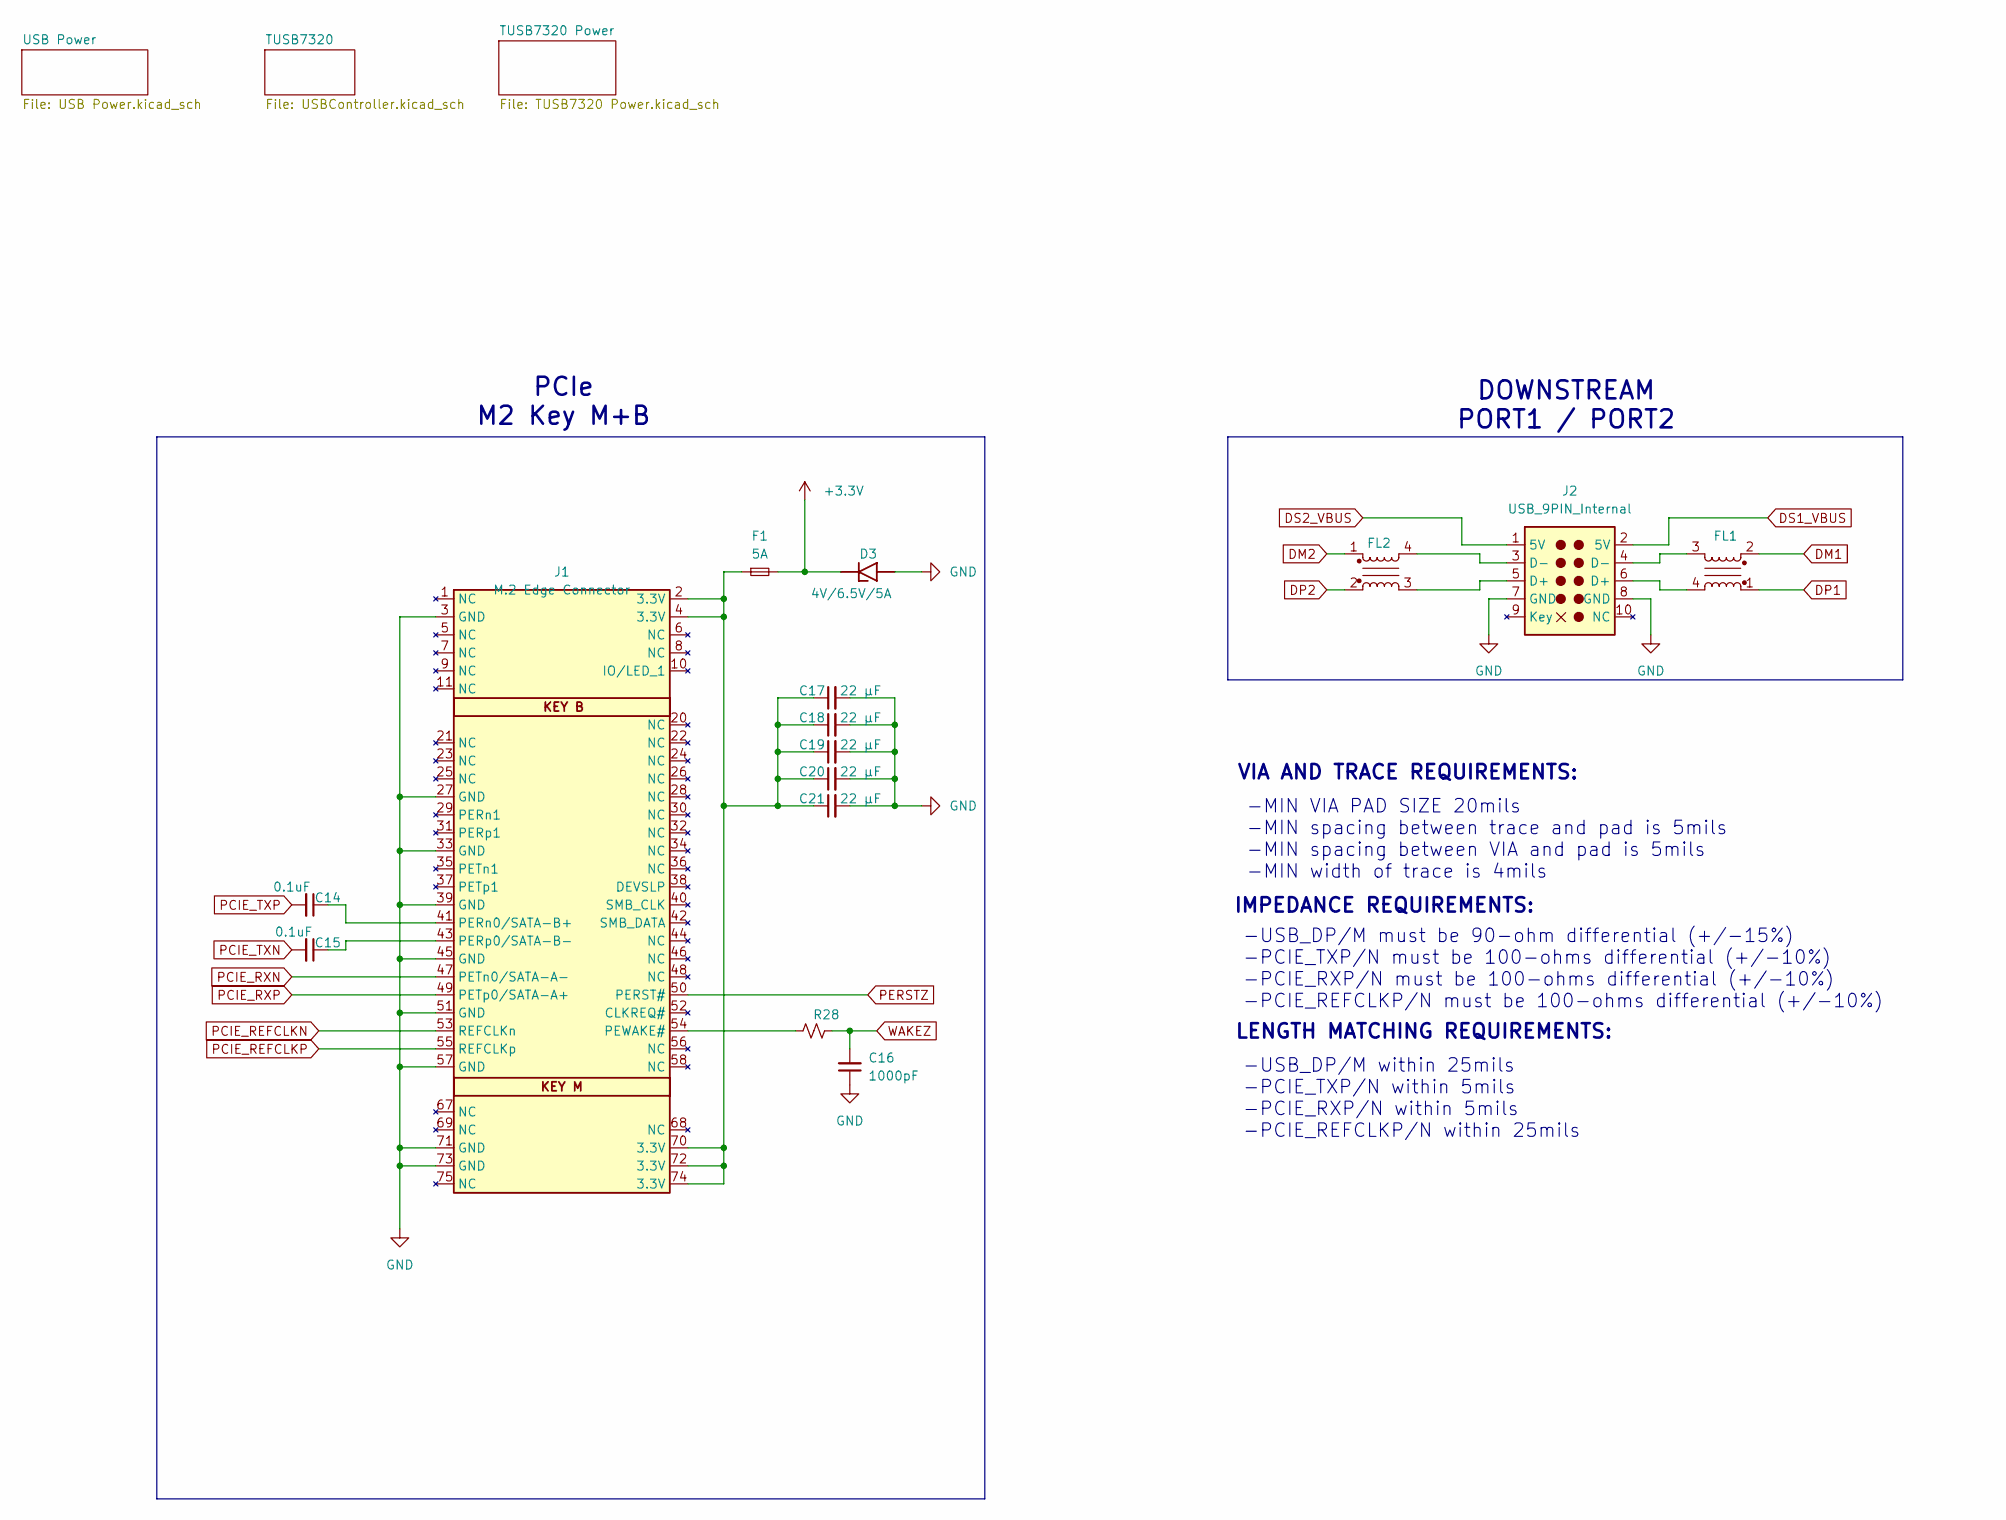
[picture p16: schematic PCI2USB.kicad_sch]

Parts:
C14, C15: 0.1uF; C_0402_1005Metric
C16: 1000pF; C_0402_1005Metric_Pad0.74x0.62mm_HandSolder
C17, C18, C19, C20, C21: 22 µF; C_0402_1005Metric
D3: 4V/6.5V/5A; PJSD0XTS-AU; Manufacturer_Part_Number PJSD03TS-AU
F1: 5A; Fuse_0603_1608Metric
FL1, FL2: 90 Ohm 160mA; MCZ1210AH201L2TA0G
J1: M.2 Edge Connector; M.2_KEY_M_B
J2: USB_9PIN_Internal; USB 9 Pin internal header
R28: 0 Ohm; R_0402_1005Metric

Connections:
+3.3V: D3.1 (K), F1.2; also elsewhere on the board
DM1: FL1.2; also elsewhere on the board
DM2: FL2.1; also elsewhere on the board
DP1: FL1.1; also elsewhere on the board
DP2: FL2.2; also elsewhere on the board
DS1_VBUS: J2.2 (5V); also elsewhere on the board
DS2_VBUS: J2.1 (5V); also elsewhere on the board
GND: C16.1, C17.2, C18.2, C19.2, C20.2, C21.2, D3.2 (A), J1.3 (GND), J1.27 (GND), J1.33 (GND), J1.39 (GND), J1.45 (GND), J1.51 (GND), J1.57 (GND), J1.71 (GND), J1.73 (GND), J2.7 (GND), J2.8 (GND); also elsewhere on the board
unnamed: C17.1, C18.1, C19.1, C20.1, C21.1, F1.1, J1.2 (3.3V), J1.4 (3.3V), J1.70 (3.3V), J1.72 (3.3V), J1.74 (3.3V)
unnamed: FL1.3, J2.4 (D-)
unnamed: FL1.4, J2.6 (D+)
unnamed: FL2.3, J2.5 (D+)
unnamed: FL2.4, J2.3 (D-)
unnamed: C14.1, J1.41 (PERn0/SATA-B+)
unnamed: C15.1, J1.43 (PERp0/SATA-B-)
unnamed: J1.54 (PEWAKE#), R28.2
PCIE_REFCLKN: J1.53 (REFCLKn); also elsewhere on the board
PCIE_REFCLKP: J1.55 (REFCLKp); also elsewhere on the board
PCIE_RXN: J1.47 (PETn0/SATA-A-); also elsewhere on the board
PCIE_RXP: J1.49 (PETp0/SATA-A+); also elsewhere on the board
PCIE_TXN: C15.2; also elsewhere on the board
PCIE_TXP: C14.2; also elsewhere on the board
PERSTZ: J1.50 (PERST#); also elsewhere on the board
WAKEZ: C16.2, R28.1; also elsewhere on the board

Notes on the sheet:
VIA AND TRACE REQUIREMENTS:
-MIN VIA PAD SIZE 20mils -MIN spacing between trace and pad is 5mils -MIN spacing between VIA and pad is 5mils -MIN width of trace is 4mils
DOWNSTREAM PORT1 / PORT2
IMPEDANCE REQUIREMENTS:
-USB_DP/M must be 90-ohm differential (+/-15%) -PCIE_TXP/N must be 100-ohms differential (+/-10%) -PCIE_RXP/N must be 100-ohms differential (+/-10%) -PCIE_REFCLKP/N must be 100-ohms differential (+/-10%)
-USB_DP/M within 25mils -PCIE_TXP/N within 5mils -PCIE_RXP/N within 5mils -PCIE_REFCLKP/N within 25mils
PCIe M2 Key M+B
LENGTH MATCHING REQUIREMENTS:

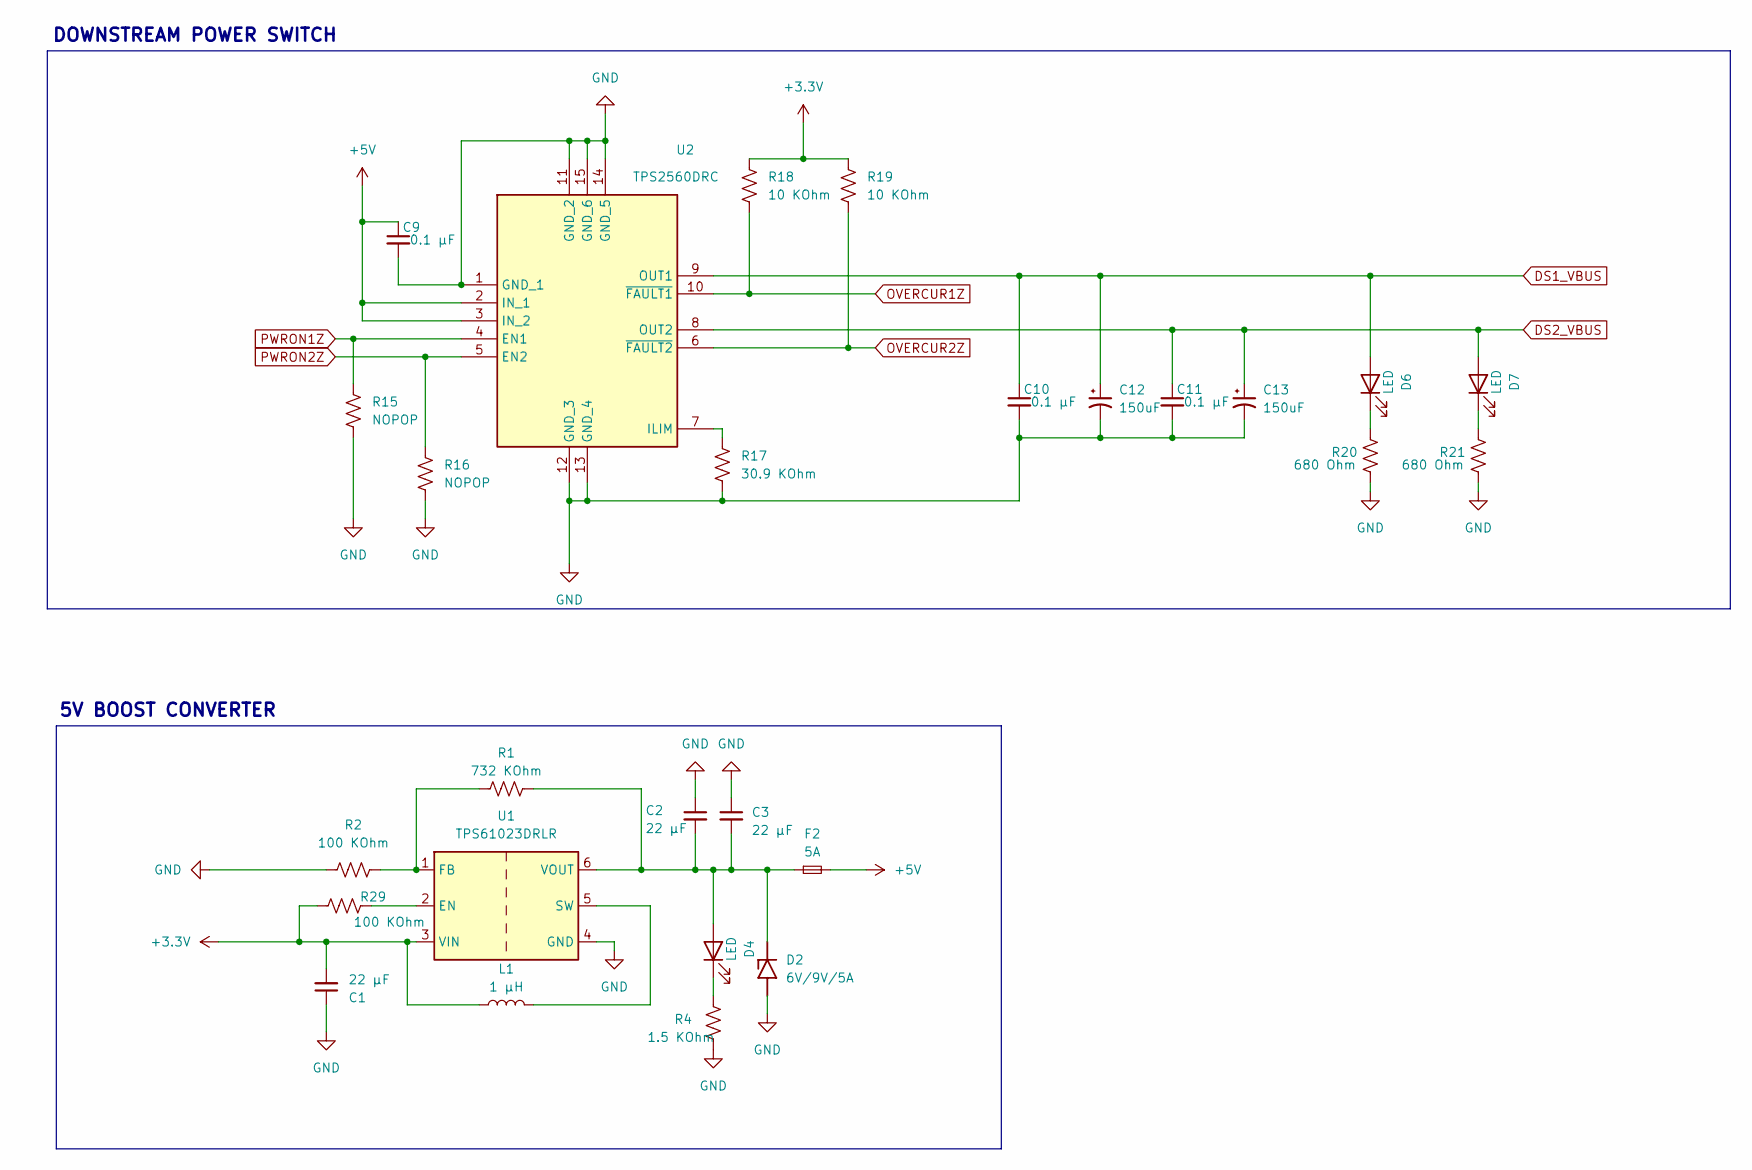
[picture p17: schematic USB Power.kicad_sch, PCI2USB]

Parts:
C1, C2, C3: 22 μF; C_0805_2012Metric
C9, C10, C11: 0.1 μF; C_0402_1005Metric
C12, C13: 150uF; CP_Elec_6.3x5.9
D2: 6V/9V/5A; PJSD0XTS-AU; Manufacturer_Part_Number PJSD03TS-AU
D4, D6, D7: LED; LED_0603_1608Metric
F2: 5A; Fuse_0603_1608Metric
L1: 1 μH; L_Chilisin_BMRx00050515
R1: 732 KOhm; R_0603_1608Metric
R2, R29: 100 KOhm; R_0402_1005Metric
R4: 1.5 KOhm; R_0402_1005Metric
R15, R16: NOPOP; R_0402_1005Metric_Pad0.72x0.64mm_HandSolder
R17: 30.9 KOhm; R_0402_1005Metric
R18, R19: 10 KOhm; R_0402_1005Metric
R20, R21: 680 Ohm; R_0402_1005Metric
U1: TPS61023DRLR
U2: TPS2560DRC; TPS2560DRCT; Manufacturer_Part_Number TPS2560DRCT; Mouser Part Number 595-TPS2560DRCT

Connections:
+3.3V: C1.2, L1.1, R18.2, R19.2, R29.1, U1.3 (VIN); also elsewhere on the board
+5V: C9.1, F2.2, U2.2 (IN_1), U2.3 (IN_2)
DS1_VBUS: C10.1, C12.1, D6.2 (A), U2.9 (OUT1); also elsewhere on the board
DS2_VBUS: C11.1, C13.1, D7.2 (A), U2.8 (OUT2); also elsewhere on the board
GND: C1.1, C2.1, C3.1, C9.2, C10.2, C11.2, C12.2, C13.2, D2.2 (A), R2.1, R4.2, R15.1, R16.1, R17.1, R20.2, R21.2, U1.4 (GND), U2.1 (GND_1), U2.11 (GND_2), U2.12 (GND_3), U2.13 (GND_4), U2.14 (GND_5), U2.15 (GND_6); also elsewhere on the board
unnamed: C2.2, C3.2, D2.1 (K), D4.2 (A), F2.1, R1.2, U1.6 (VOUT)
unnamed: D4.1 (K), R4.1
unnamed: D6.1 (K), R20.1
unnamed: D7.1 (K), R21.1
unnamed: R29.2, U1.2 (EN)
unnamed: R1.1, R2.2, U1.1 (FB)
unnamed: L1.2, U1.5 (SW)
unnamed: R17.2, U2.7 (ILIM)
OVERCUR1Z: R18.1, U2.10 (~FAULT1); also elsewhere on the board
OVERCUR2Z: R19.1, U2.6 (~FAULT2); also elsewhere on the board
PWRON1Z: R15.2, U2.4 (EN1); also elsewhere on the board
PWRON2Z: R16.2, U2.5 (EN2); also elsewhere on the board

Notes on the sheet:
5V BOOST CONVERTER
DOWNSTREAM POWER SWITCH

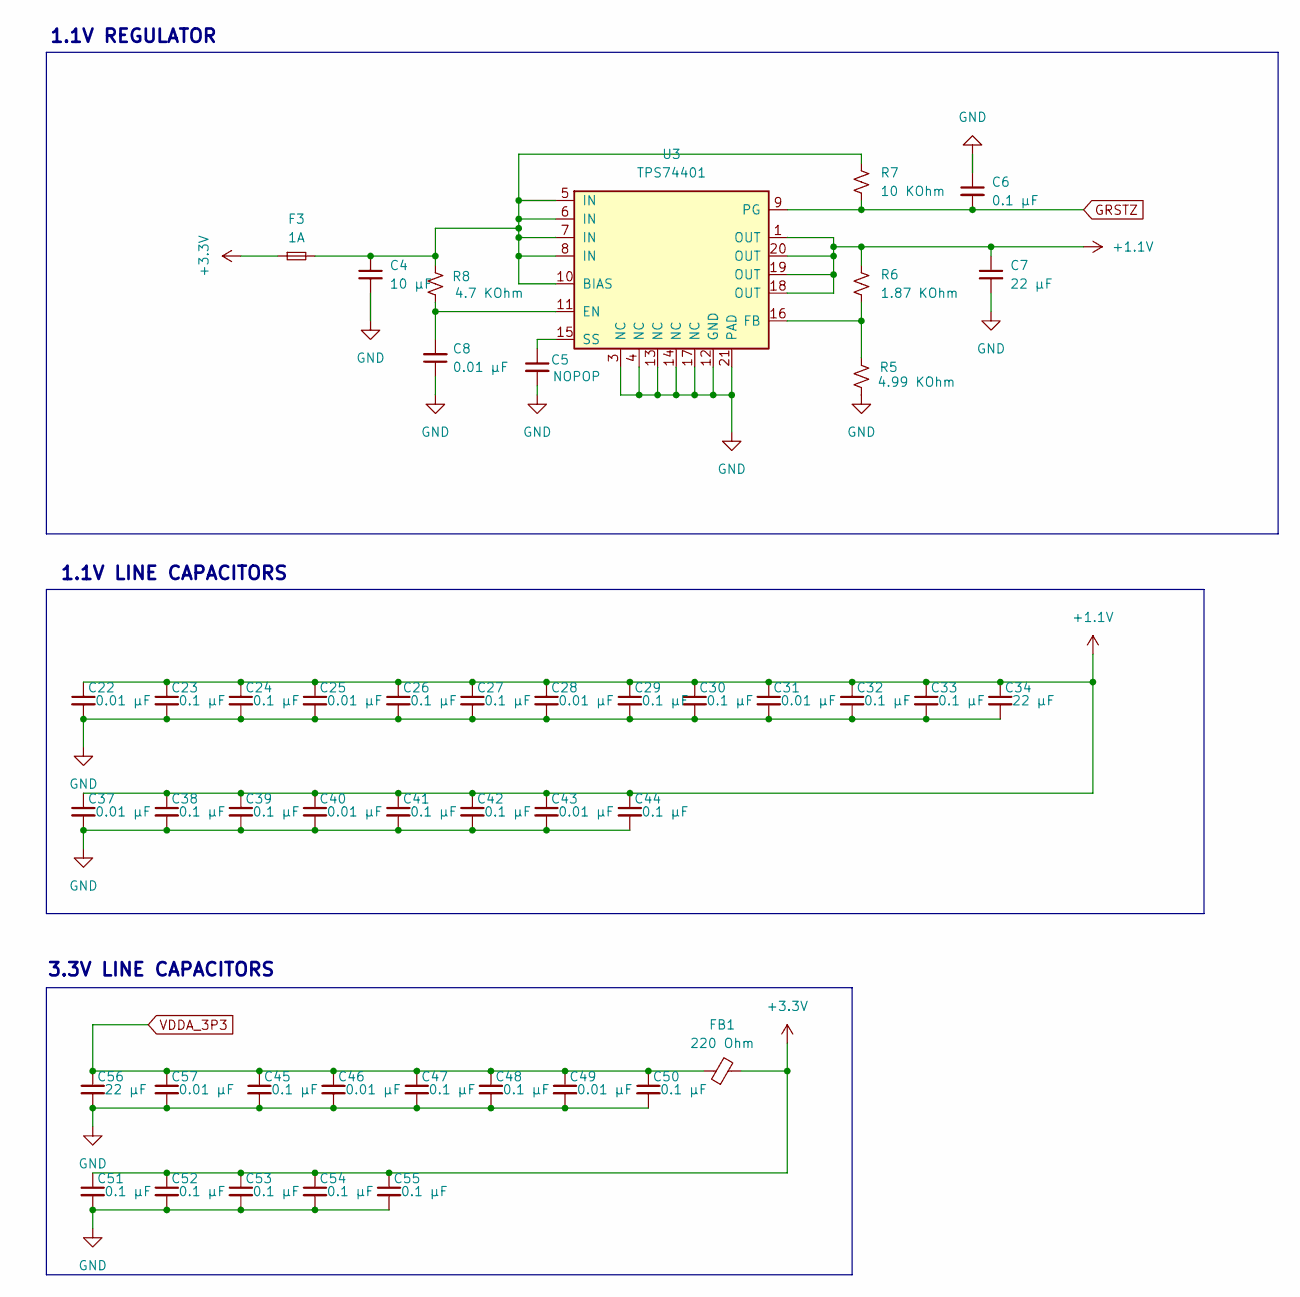
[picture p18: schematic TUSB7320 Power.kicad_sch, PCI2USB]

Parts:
C4: 10 μF; C_0805_2012Metric
C5: NOPOP; C_0402_1005Metric_Pad0.74x0.62mm_HandSolder
C6, C23, C24, C26, C27, C29, C30, C32, C33, C38, C39, C41, C42, C44, C45, C47, C48, C50, C51, C52, C53, C54, C55: 0.1 μF; C_0402_1005Metric
C7, C34, C56: 22 μF; C_0805_2012Metric
C8, C22, C25, C28, C31, C37, C40, C43, C46, C49, C57: 0.01 μF; C_0402_1005Metric
F3: 1A; Fuse_0603_1608Metric
FB1: 220 Ohm; L_0603_1608Metric
R5: 4.99 KOhm; R_0402_1005Metric
R6: 1.87 KOhm; R_0402_1005Metric
R7: 10 KOhm; R_0402_1005Metric
R8: 4.7 KOhm; R_0402_1005Metric
U3: TPS74401; TPS74401RGWRM3

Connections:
+1.1V: C7.1, C22.1, C23.1, C24.1, C25.1, C26.1, C27.1, C28.1, C29.1, C30.1, C31.1, C32.1, C33.1, C34.1, C37.1, C38.1, C39.1, C40.1, C41.1, C42.1, C43.1, C44.1, R6.1, U3.1 (OUT), U3.18 (OUT), U3.19 (OUT), U3.20 (OUT); also elsewhere on the board
+3.3V: C51.1, C52.1, C53.1, C54.1, C55.1, F3.1, FB1.2; also elsewhere on the board
GND: C4.2, C5.2, C6.1, C7.2, C8.1, C22.2, C23.2, C24.2, C25.2, C26.2, C27.2, C28.2, C29.2, C30.2, C31.2, C32.2, C33.2, C34.2, C37.2, C38.2, C39.2, C40.2, C41.2, C42.2, C43.2, C44.2, C45.2, C46.2, C47.2, C48.2, C49.2, C50.2, C51.2, C52.2, C53.2, C54.2, C55.2, C56.2, C57.2, R5.1, U3.3 (NC), U3.4 (NC), U3.12 (GND), U3.13 (NC), U3.14 (NC), U3.17 (NC), U3.21 (PAD); also elsewhere on the board
GRSTZ: C6.2, R7.2, U3.9 (PG); also elsewhere on the board
unnamed: C4.1, F3.2, R7.1, R8.1, U3.5 (IN), U3.6 (IN), U3.7 (IN), U3.8 (IN), U3.10 (BIAS)
unnamed: C8.2, R8.2, U3.11 (EN)
unnamed: R5.2, R6.2, U3.16 (FB)
unnamed: C5.1, U3.15 (SS)
VDDA_3P3: C45.1, C46.1, C47.1, C48.1, C49.1, C50.1, C56.1, C57.1, FB1.1; also elsewhere on the board

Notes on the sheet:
1.1V LINE CAPACITORS
1.1V REGULATOR
3.3V LINE CAPACITORS

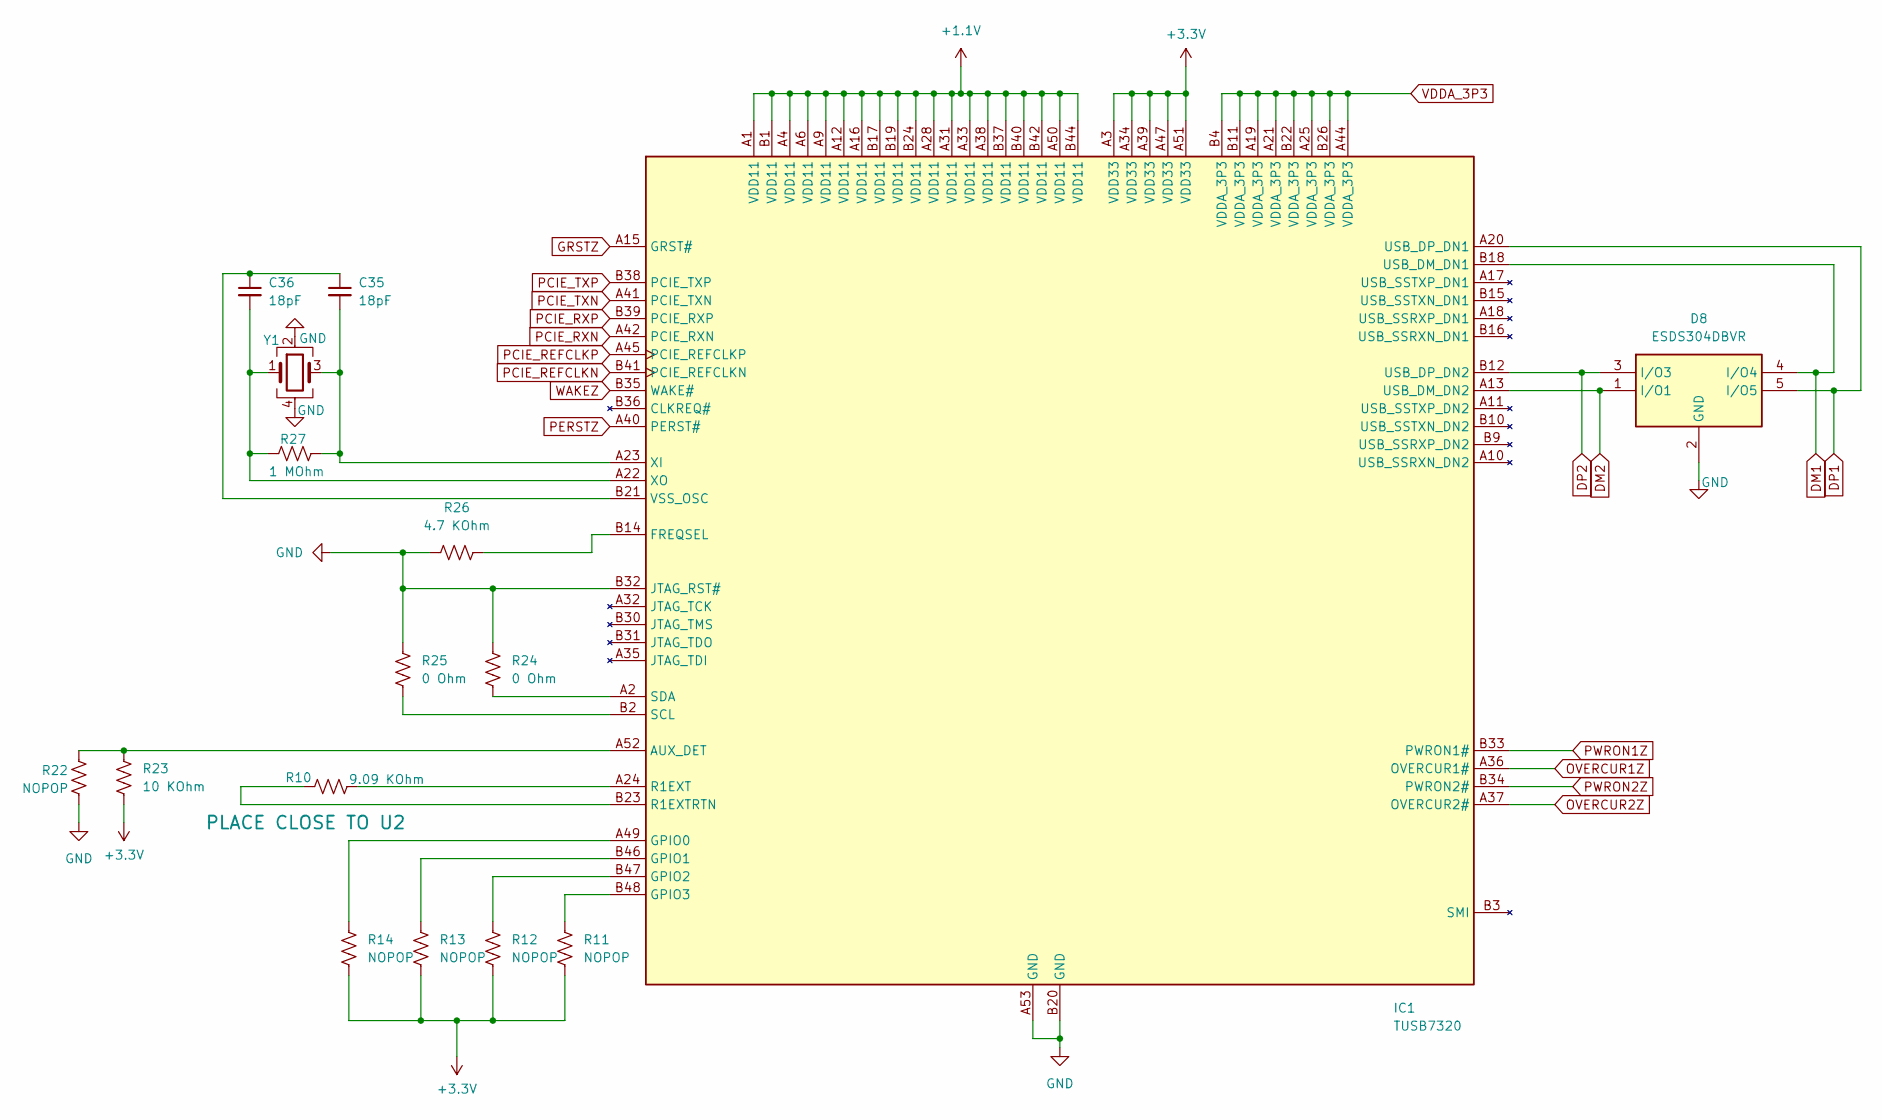
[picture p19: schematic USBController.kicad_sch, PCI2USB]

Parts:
C35, C36: 18pF; C_0402_1005Metric
D8: ESDS304DBVR; Manufacturer_Part_Number ESDS304DBVR; Mouser Part Number 595-ESDS304DBVR
IC1: TUSB7320; TUSB7320RKMT; Manufacturer_Part_Number TUSB7320RKMT; Mouser Part Number 595-TUSB7320RKMT
R10: 9.09 KOhm; R_0402_1005Metric
R11, R12, R13, R14, R22: NOPOP; R_0402_1005Metric_Pad0.72x0.64mm_HandSolder
R23: 10 KOhm; R_0402_1005Metric
R24, R25: 0 Ohm; R_0402_1005Metric
R26: 4.7 KOhm; R_0402_1005Metric
R27: 1 MOhm; R_0402_1005Metric
Y1: 48 MHz; ABM3B-48.000MHZ-B2-T

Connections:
+1.1V: IC1.A1 (VDD11), IC1.A4 (VDD11), IC1.A6 (VDD11), IC1.A9 (VDD11), IC1.A12 (VDD11), IC1.A16 (VDD11), IC1.A28 (VDD11), IC1.A31 (VDD11), IC1.A33 (VDD11), IC1.A38 (VDD11), IC1.A50 (VDD11), IC1.B1 (VDD11), IC1.B17 (VDD11), IC1.B19 (VDD11), IC1.B24 (VDD11), IC1.B37 (VDD11), IC1.B40 (VDD11), IC1.B42 (VDD11), IC1.B44 (VDD11); also elsewhere on the board
+3.3V: IC1.A3 (VDD33), IC1.A34 (VDD33), IC1.A39 (VDD33), IC1.A47 (VDD33), IC1.A51 (VDD33), R11.1, R12.1, R13.1, R14.1, R23.2; also elsewhere on the board
DM1: D8.4 (I/O4), IC1.B18 (USB_DM_DN1); also elsewhere on the board
DM2: D8.1 (I/O1), IC1.A13 (USB_DM_DN2); also elsewhere on the board
DP1: D8.5 (I/O5), IC1.A20 (USB_DP_DN1); also elsewhere on the board
DP2: D8.3 (I/O3), IC1.B12 (USB_DP_DN2); also elsewhere on the board
GND: D8.2 (GND), IC1.A53 (GND), IC1.B20 (GND), IC1.B32 (JTAG_RST#), R22.2, R24.2, R25.2, R26.1, Y1.2, Y1.4; also elsewhere on the board
GRSTZ: IC1.A15 (GRST#); also elsewhere on the board
unnamed: IC1.A52 (AUX_DET), R22.1, R23.1
unnamed: IC1.B14 (FREQSEL), R26.2
unnamed: IC1.A49 (GPIO0), R14.2
unnamed: IC1.B46 (GPIO1), R13.2
unnamed: IC1.B47 (GPIO2), R12.2
unnamed: IC1.B48 (GPIO3), R11.2
unnamed: IC1.A24 (R1EXT), R10.1
unnamed: IC1.B23 (R1EXTRTN), R10.2
unnamed: IC1.B2 (SCL), R25.1
unnamed: IC1.A2 (SDA), R24.1
unnamed: C35.1, C36.1, IC1.B21 (VSS_OSC)
unnamed: C35.2, IC1.A23 (XI), R27.2, Y1.3
unnamed: C36.2, IC1.A22 (XO), R27.1, Y1.1
OVERCUR1Z: IC1.A36 (OVERCUR1#); also elsewhere on the board
OVERCUR2Z: IC1.A37 (OVERCUR2#); also elsewhere on the board
PCIE_REFCLKN: IC1.B41 (PCIE_REFCLKN); also elsewhere on the board
PCIE_REFCLKP: IC1.A45 (PCIE_REFCLKP); also elsewhere on the board
PCIE_RXN: IC1.A42 (PCIE_RXN); also elsewhere on the board
PCIE_RXP: IC1.B39 (PCIE_RXP); also elsewhere on the board
PCIE_TXN: IC1.A41 (PCIE_TXN); also elsewhere on the board
PCIE_TXP: IC1.B38 (PCIE_TXP); also elsewhere on the board
PERSTZ: IC1.A40 (PERST#); also elsewhere on the board
PWRON1Z: IC1.B33 (PWRON1#); also elsewhere on the board
PWRON2Z: IC1.B34 (PWRON2#); also elsewhere on the board
VDDA_3P3: IC1.A19 (VDDA_3P3), IC1.A21 (VDDA_3P3), IC1.A25 (VDDA_3P3), IC1.A44 (VDDA_3P3), IC1.B4 (VDDA_3P3), IC1.B11 (VDDA_3P3), IC1.B22 (VDDA_3P3), IC1.B26 (VDDA_3P3); also elsewhere on the board
WAKEZ: IC1.B35 (WAKE#); also elsewhere on the board

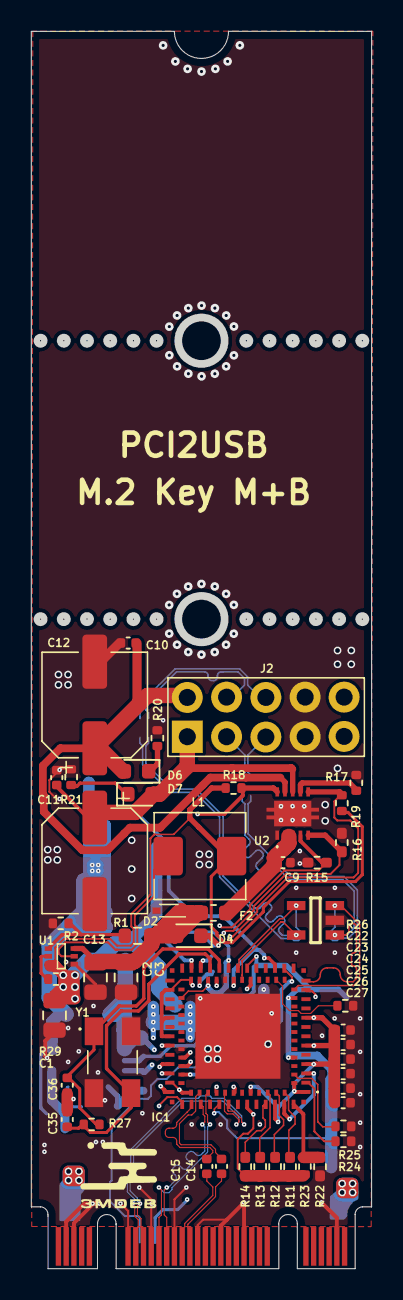
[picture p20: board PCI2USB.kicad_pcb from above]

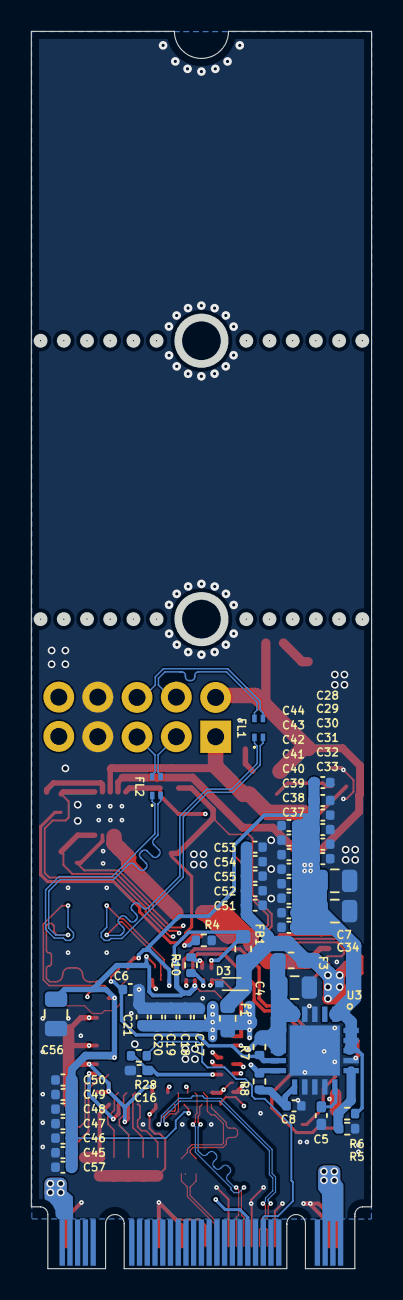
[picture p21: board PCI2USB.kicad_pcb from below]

Board: 4 copper layers, 22.0 x 80.0 mm, 104 parts (53 on the bottom side), 57 nets.

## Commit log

2025-10-16 Uploading initial PCI2USB proejct files
    [BOM.xls, PCI2USB.kicad_pcb, PCI2USB.kicad_sch]
2025-10-16 Updated schematics and board layout
    [BOM.xls, PCI2USB.kicad_pcb, PCI2USB.kicad_sch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]
2025-10-23 Fixed DRC Warnings and Errors
    [PCI2USB.kicad_pcb]
2025-10-27 Created schematics for 1.1V circuit
    [BOM.xls, PCI2USB.kicad_pcb, PCI2USB.kicad_sch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]
2025-10-29 Created 1.1V Circuit for USB Host IC
    [BOM.xls, PCI2USB.kicad_pcb, PCI2USB.kicad_sch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]
2025-10-29 Updated schematics for 1.1V circuit
    [PCI2USB.kicad_pcb, Signals.kicad_sch, untitled.kicad_sch]
2025-11-07 Fixed signal integrity for USB data lines
    [PCI2USB.kicad_pcb, PCI2USB.kicad_sch, Signals.kicad_sch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]
2025-11-13 Created schematics for TUSB7320 USB Controller
    [1.1V Circuit.kicad_sch, PCI2USB.kicad_sch, Power Section.kicad_sch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]
2025-11-17 Complete Schematics and BOM
    [BOM.xls, PCI2USB.kicad_sch, TUSB7320 Power.kicad_sch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]
2025-11-17 Placed additional information to board schematics
    [PCI2USB.kicad_sch, TUSB7320 Power.kicad_sch]
2025-11-20 updated BOM
    [BOM.xls]
2025-11-20 Updated PCB Design
    [PCI2USB.kicad_pcb, PCI2USB.kicad_sch, USBController.kicad_sch]
2025-11-24 Updated PCB
    [PCI2USB.kicad_pcb]
2025-11-26 created final PCB design
    [PCI2USB.kicad_pcb]
2025-11-26 Fixed VIAs around screw holes
    [PCI2USB.kicad_pcb]
2025-11-26 Updated 3D models
    [ABM3B-48.000MHZ-B2-T.stp, APHD1608LCGCK.stp, APHD1608LSURCK.stp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]
2025-12-01 Cleaned custom libraries, fixed footprint and 3d models
    [BOM.xls, PCI2USB.kicad_sch, PJSD05TS.stp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]
2025-12-04 Redesigned PCB compliant with PCI and SS USB standards
    [1.1V Circuit.kicad_sch, BOM.xls, PCI2USB.kicad_pcb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]
2025-12-08 Fixed reversed 9 pin connector
    [BOM.xls, PCI2USB.kicad_pcb, PCI2USB.kicad_sch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]
2025-12-08 Fixed USB pair crosing with other net
    [PCI2USB.kicad_pcb]
2025-12-08 Updated 3D models and Logo
    [PCI2USB.kicad_pcb]
2025-12-08 Moved USB connector to acheive wider 5V traces
    [PCI2USB.kicad_pcb]
2025-12-08 removed temporary files
    [TPS2560DRCT.stp, TPS74401RGWRM3.stp]
2025-12-08 fixed pdf schematics, removed temporary files
    [BOM.xls, PCI2USB.kicad_pcb, PCI2USB.kicad_sch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]
2025-12-08 Created all necessary production files
    [BOM.xls, Board&Layers.xls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]
2026-03-02 Updated MPN for a few Capacitors
    [BOM.xls, BOM_with_pricing.xls, PCI2USB.kicad_sch]
2026-03-02 Removed duplicated components in BOM
    [BOM.xls]
2026-03-27 Change parameters of board thickness
    [Board&Layers.xls]
2026-03-27 Added more thermal relief points, and bigger power traces
    [PCI2USB.kicad_pcb]
2026-03-27 Updated all SMD footprints to not hand soldered versions
    [PCI2USB.kicad_pcb, PCI2USB.kicad_sch, TUSB7320 Power.kicad_sch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]
2026-03-27 the breakout holes were shrunk down
    [PCI2USB.kicad_pcb]
2026-03-27 generated new production files
    [PCI2USB-B_Cu.gbr, PCI2USB-B_Mask.gbr, PCI2USB-B_Paste.gbr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]
2026-10-26 Redesigned schematic and board REV 2.0
